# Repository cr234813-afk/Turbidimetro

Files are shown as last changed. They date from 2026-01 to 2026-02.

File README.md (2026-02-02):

# Turbidimetro
El acceso a agua de calidad es un pilar fundamental para el desarrollo sostenible y la salud pública; sin embargo, el monitoreo constante de cuerpos hídricos enfrenta barreras económicas debido al alto costo de los equipos de medición certificados. En este contexto, la turbidez, definida como la medida del grado de transparencia que pierde el agua por la presencia de partículas en suspensión, se presenta como uno de los indicadores más críticos para evaluar la potabilidad y el estado ecológico de los ecosistemas acuáticos.
El presente proyecto, surge como una respuesta tecnológica de bajo costo y código abierto. El núcleo del dispositivo se fundamenta en el método de transmitancia. Para garantizar el diseño conceptual se validó mediante herramientas de ingeniería como el QFD y matrices de selección como del apoyo del laboratorio de la EMAPS donde se realizaron algunas pruebas con un turbidímetro comercial, asegurando que nuestro prototipo pueda medir el valor de turbidez, sino también portátil y sencillo de utilizar en entornos de campo.
A diferencia de otros proyectos, integra un componente de ciencia ciudadana mediante una plataforma digital desarrollada en Google Sites y GitHub que son plataformas gratuitas. Esta infraestructura permite que los datos recolectados por los usuarios sean subidos mediante formularios dinámicos y visualizados en tiempo real en estas plataformas, fomentando la participación comunitaria en la vigilancia ambiental.

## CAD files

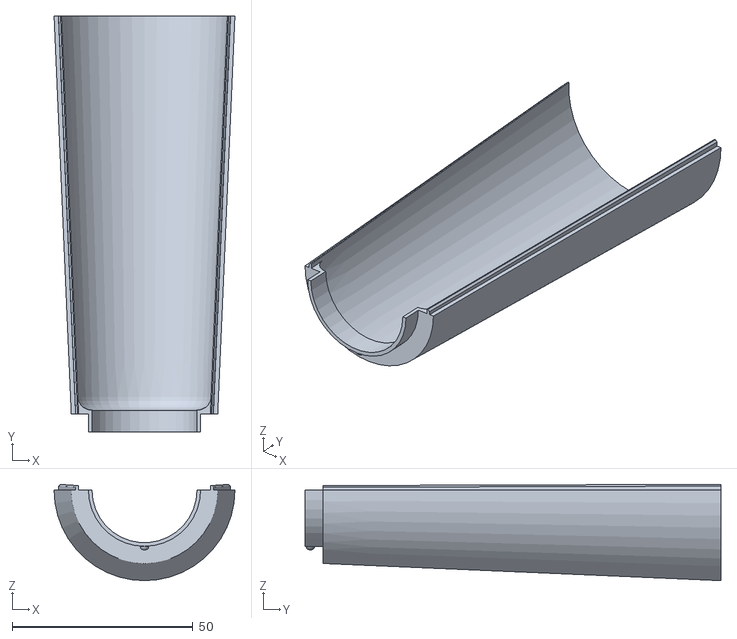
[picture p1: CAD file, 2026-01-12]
Imprimibles/Cuerpo_izquierdo.stl
50.0 x 115.0 x 26.6

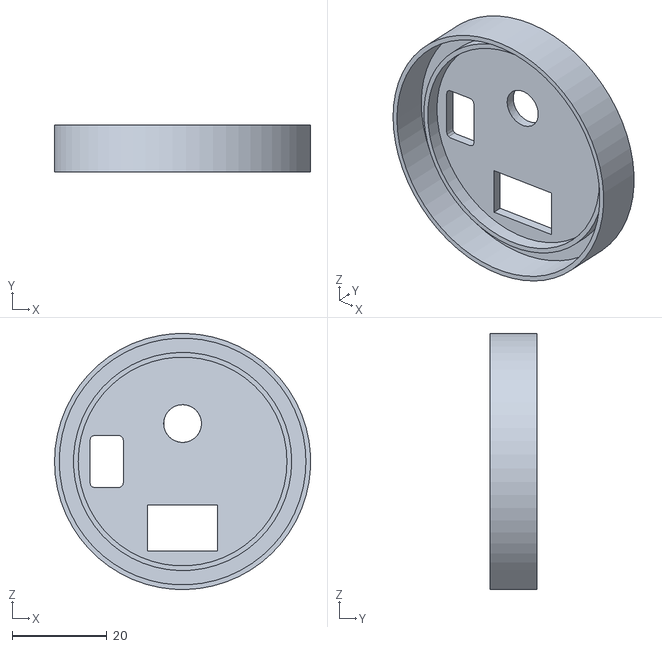
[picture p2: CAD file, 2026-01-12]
Imprimibles/Tapa_Superior.stl
54.0 x 10.0 x 54.0

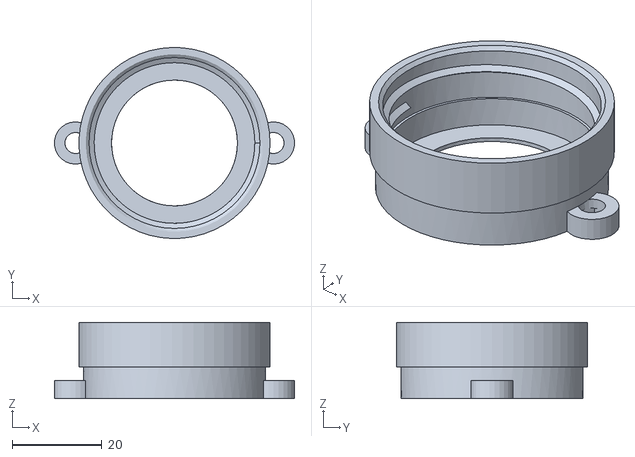
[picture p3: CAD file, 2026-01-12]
Imprimibles/Cuerpo_sensor_inferior.stl
53.4 x 42.5 x 17.0

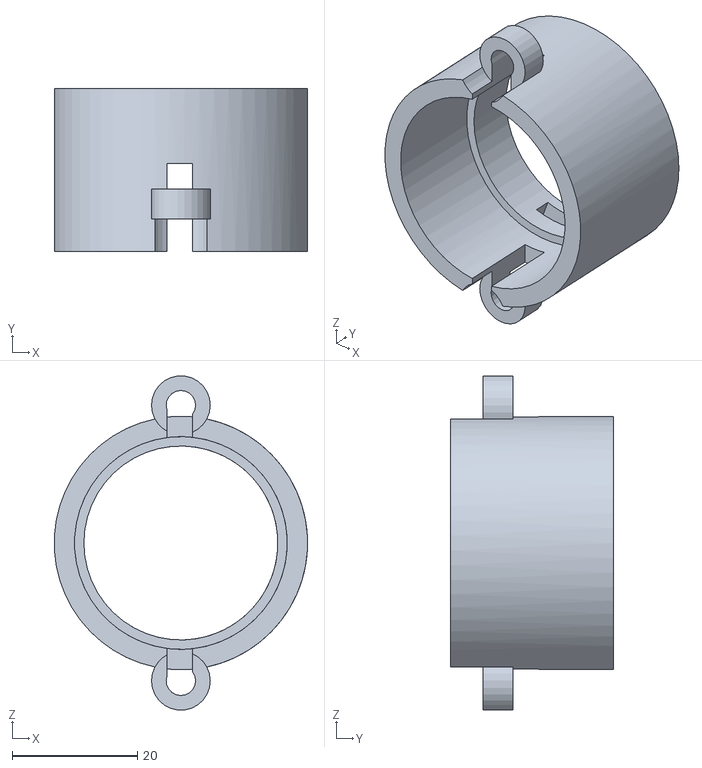
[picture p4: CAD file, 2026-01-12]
Imprimibles/Cuerpo_sensor_superior.stl
40.5 x 26.0 x 53.4

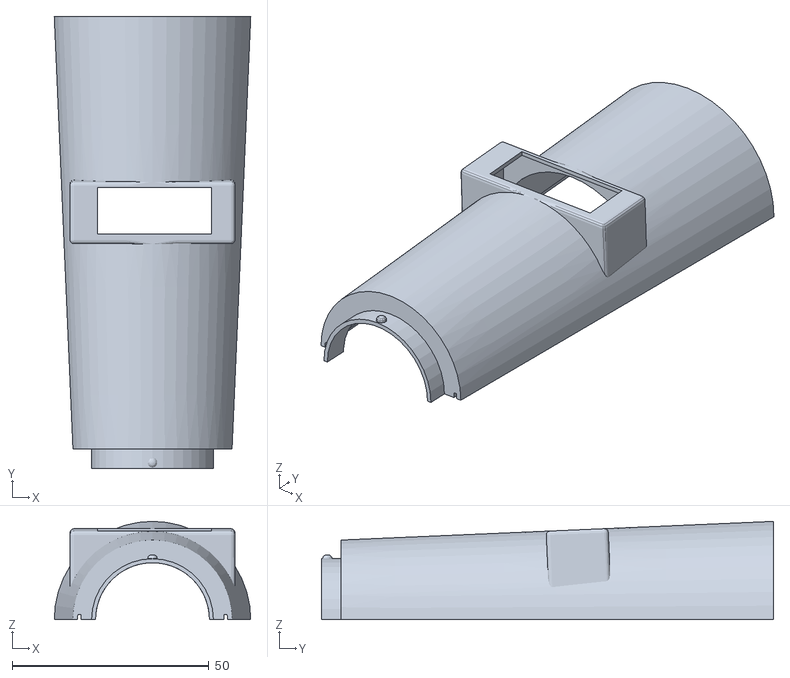
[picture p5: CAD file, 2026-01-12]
Imprimibles/Cuerpo_derecho.stl
50.0 x 115.0 x 25.0

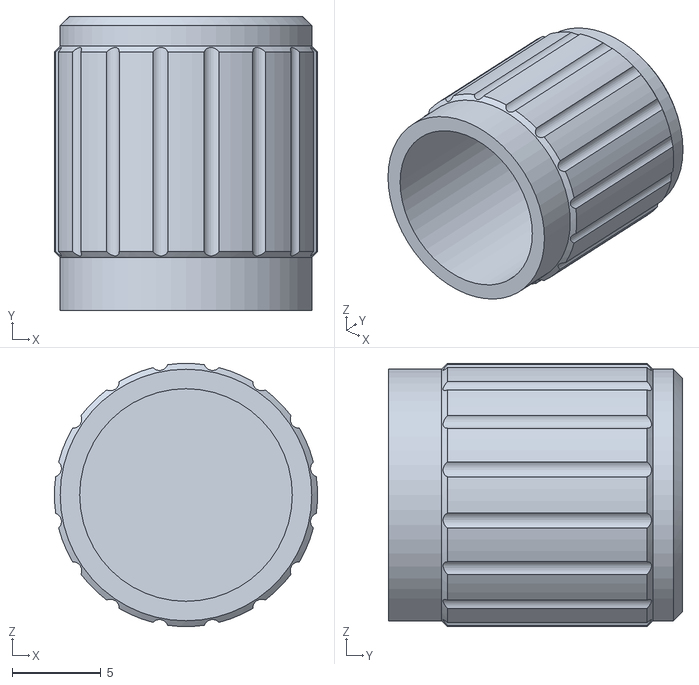
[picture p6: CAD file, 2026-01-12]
Imprimibles/Perilla_1.stl
14.8 x 16.6 x 14.8

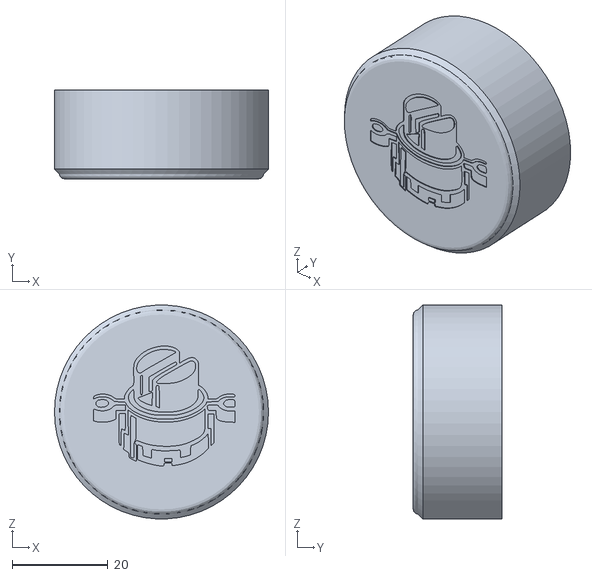
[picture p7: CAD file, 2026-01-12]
Imprimibles/Tapa_inferior.stl
44.7 x 18.5 x 44.6

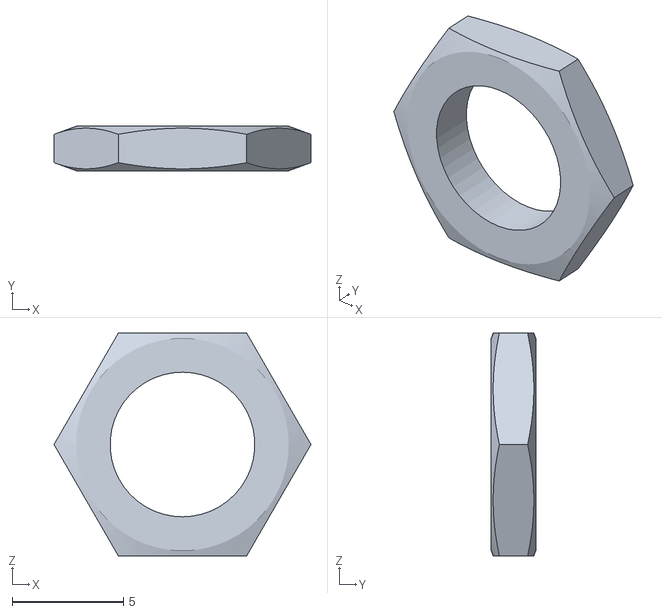
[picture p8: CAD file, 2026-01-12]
Imprimibles/Tuerca_sujecion.stl
11.5 x 2.00 x 10.0

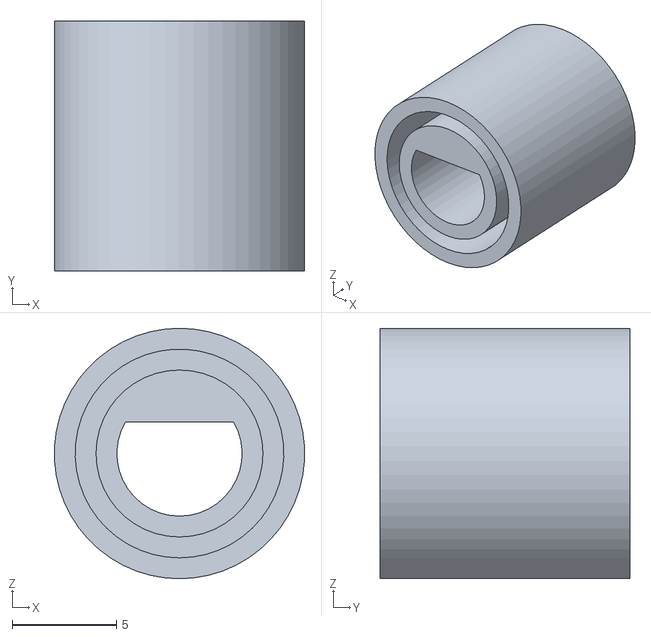
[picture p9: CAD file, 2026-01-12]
Imprimibles/Perilla_2.stl
12.0 x 12.0 x 12.0

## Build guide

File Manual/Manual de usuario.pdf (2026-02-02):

# Manual de usuario

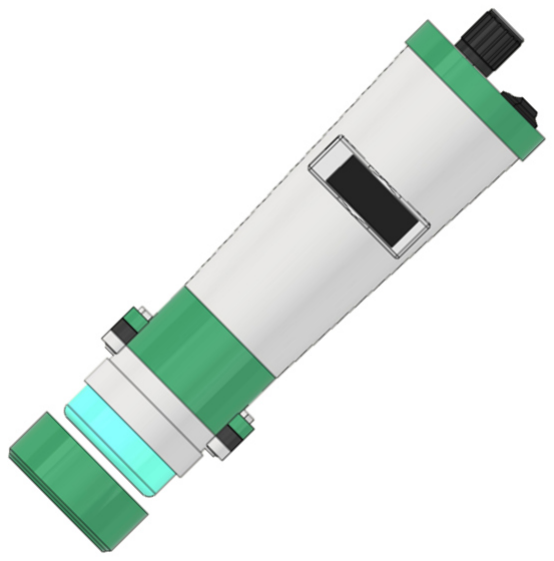
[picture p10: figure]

# Índice

### - Introducción - Requisitos previos - Lista de Materiales - Instrucciones de Impresión 3D - Calibración - Electrónica y Cableado - Programación - Montaje - Solución de Problemas - Conclusión y Contribuciones

# Introducción

- ¿Alguna vez te has preguntado cómo miden qué tan limpia está el agua? Para eso se usa el turbidímetro. Es un equipo que analiza la cantidad de partículas suspendidas en un líquido para saber qué tan transparente es realmente.
- El objetivo de este proyecto es desarrollar un turbidímetro de código abierto que rompa las barreras de costo y acceso a tecnología científica de calidad del Ecuador. A diferencia de los equipos comerciales, que suelen ser costosos y cerrados, este dispositivo combina la versatilidad de la impresión 3D con la potencia de la electrónica accesible y la programación.

# Requisitos previos

Impresora 3D

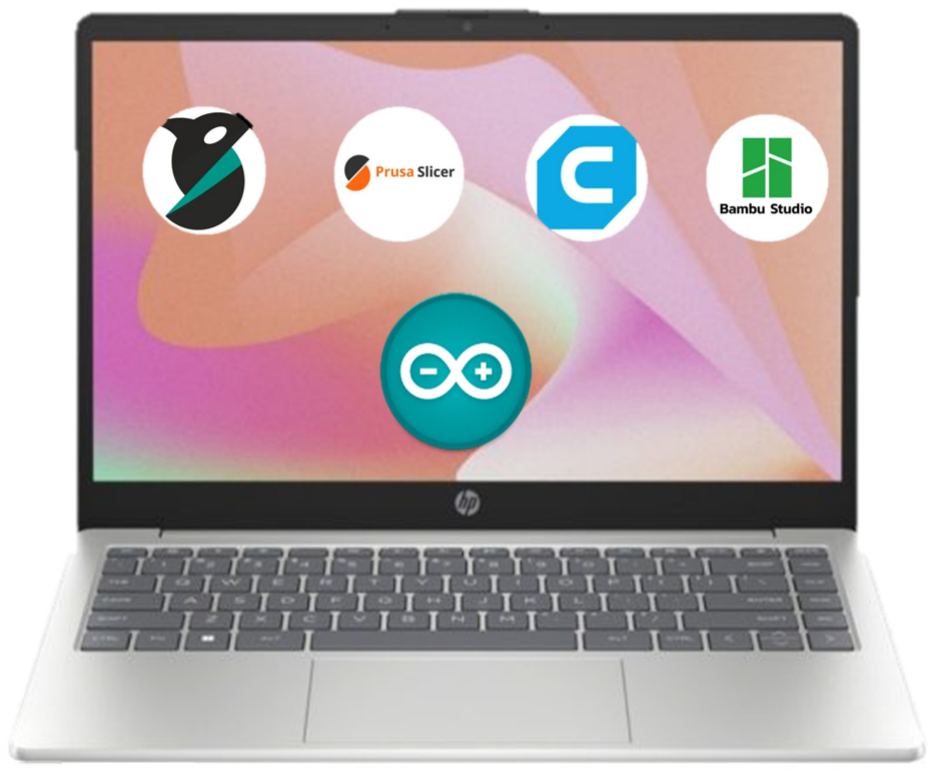
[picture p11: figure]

Computadora

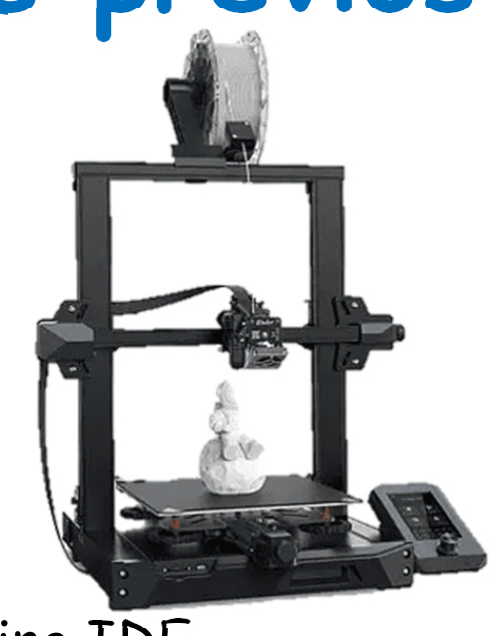
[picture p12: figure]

Software Arduino IDE

Software Slicer 3D

Kit de soldadura

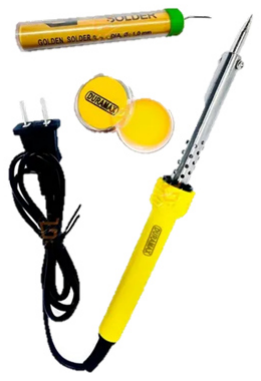
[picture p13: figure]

# Lista de partes y materiales

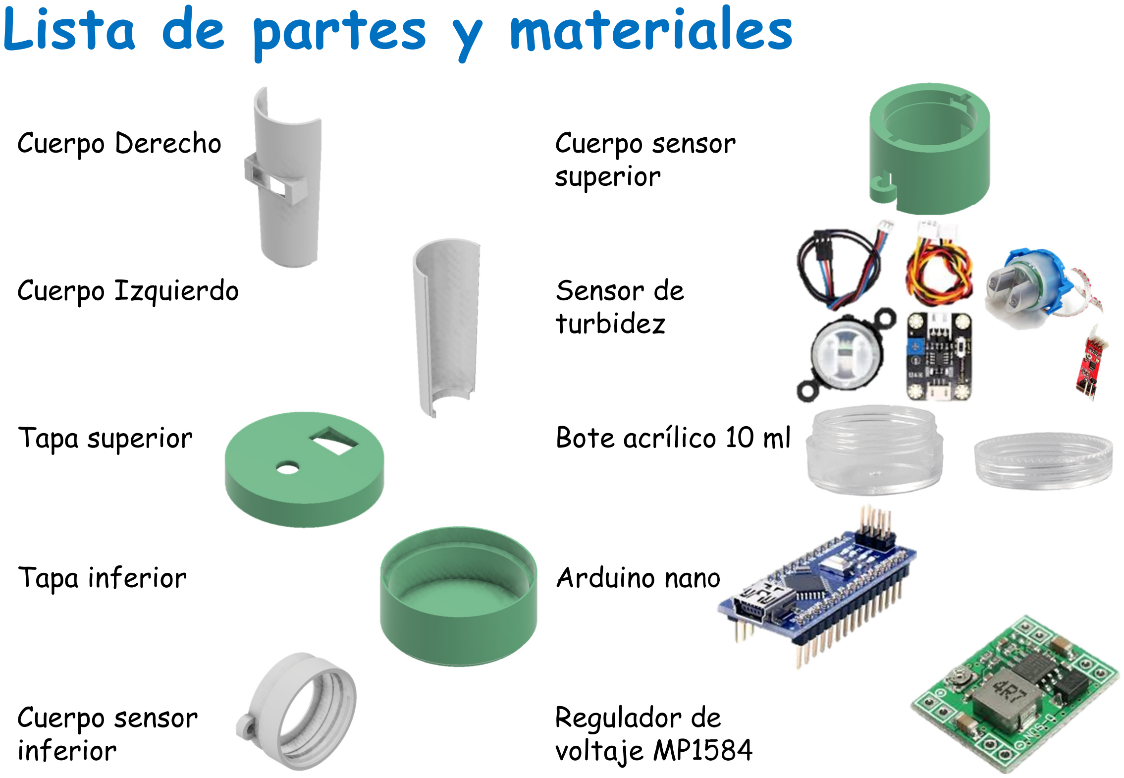
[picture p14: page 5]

Cuerpo sensor
superior

Cuerpo Derecho

Sensor de
turbidez

Cuerpo Izquierdo

Bote acrílico 10 mlTapa superior

Arduino nanoTapa inferior

Regulador de
voltaje MP1584

Cuerpo sensor
inferior

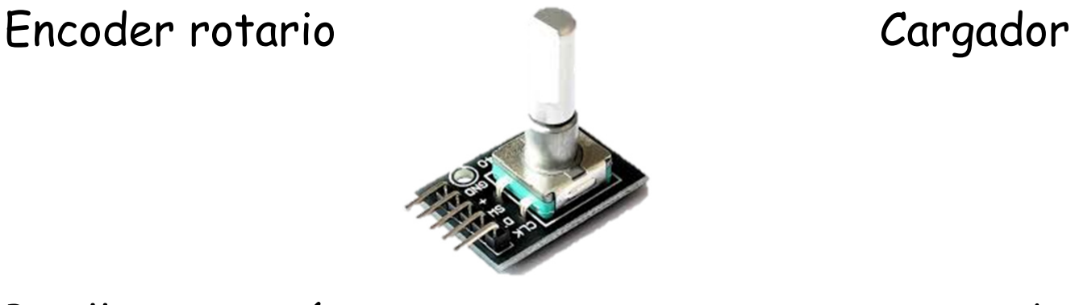
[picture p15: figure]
CargadorEncoder rotario
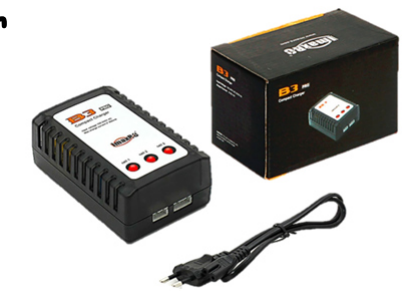
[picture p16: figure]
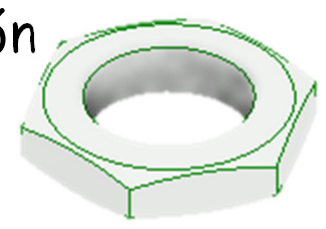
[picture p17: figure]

Turca de sujeción Perilla potenciómetro

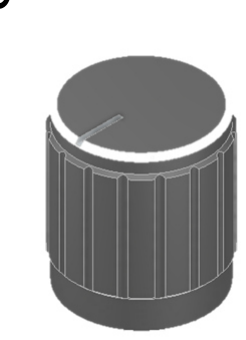
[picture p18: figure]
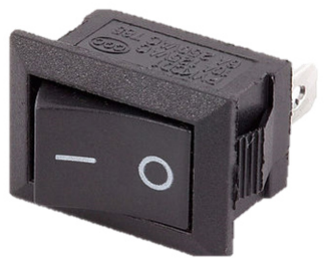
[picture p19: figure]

Inserto M4Switch

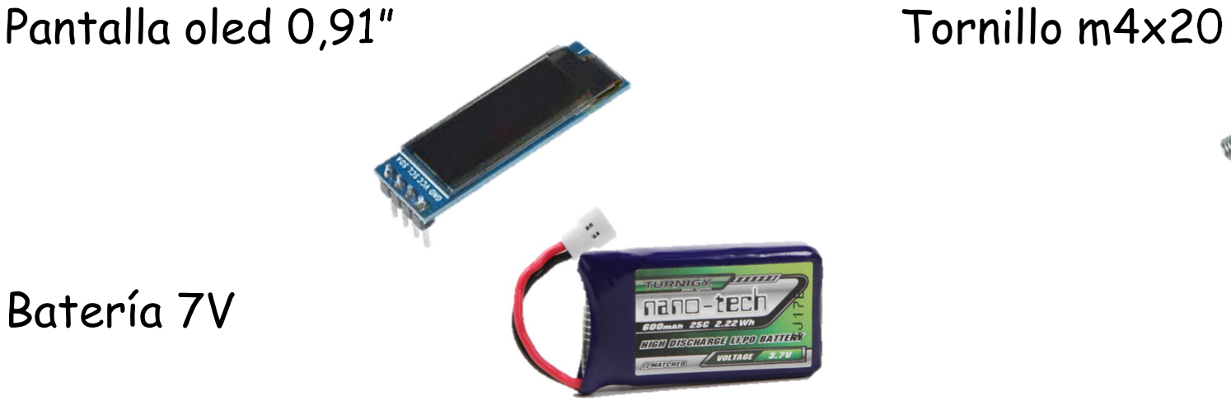
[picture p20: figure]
Tornillo m4x20Pantalla oled 0,91”; Batería 7V

# Instrucciones de Impresión 3D

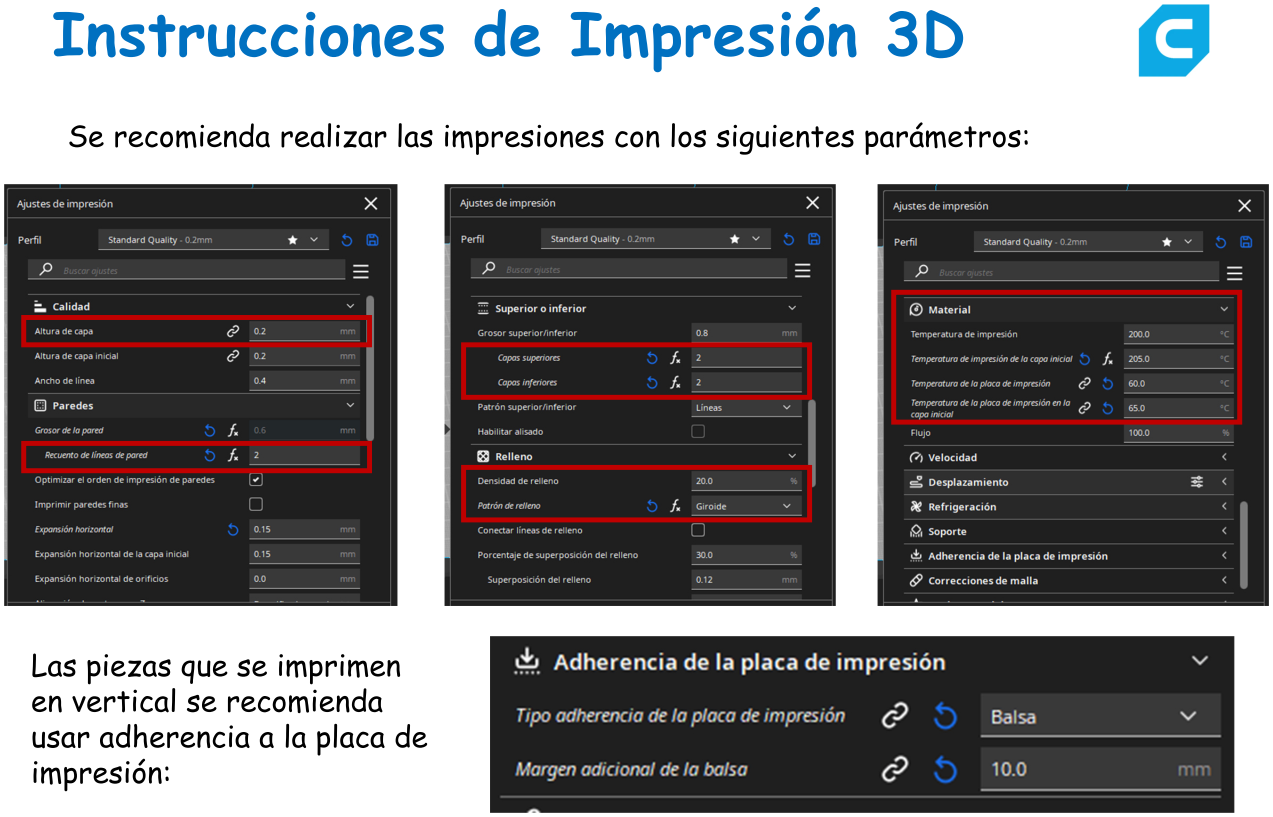
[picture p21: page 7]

Se recomienda realizar las impresiones con los siguientes parámetros:

Las piezas que se imprimen en vertical se recomienda
usar adherencia a la placa de impresión:

# Electrónica y Cableado

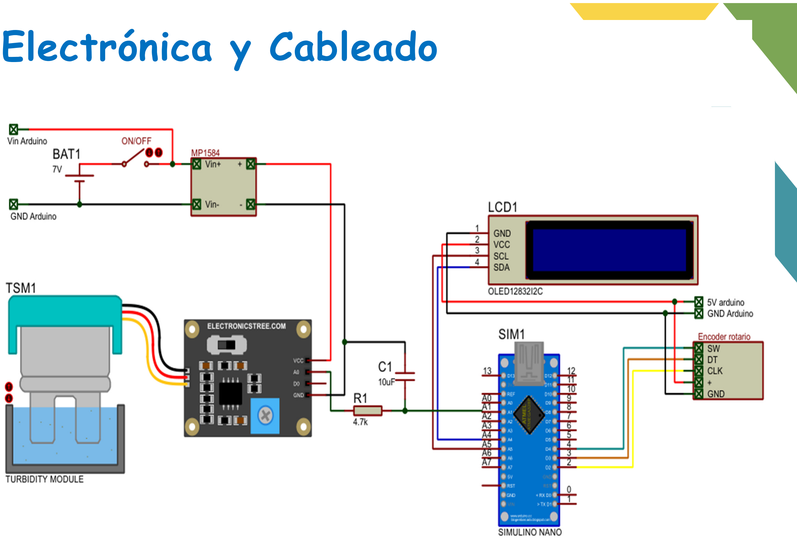
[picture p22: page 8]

### 1. Cargamos el programa Calibración_previa

### 2. Colocamos una muestra de agua destilada

### 3. Cargamos el programa y revisamos en el serial que el voltaje

sea 4,2 V

### 4. Si no esta cerca de este valor vamos a girar la perilla de la

placa de acondicionamiento hasta que cambie en el serial

### 5. Listo tu turbidímetro esta calibrado

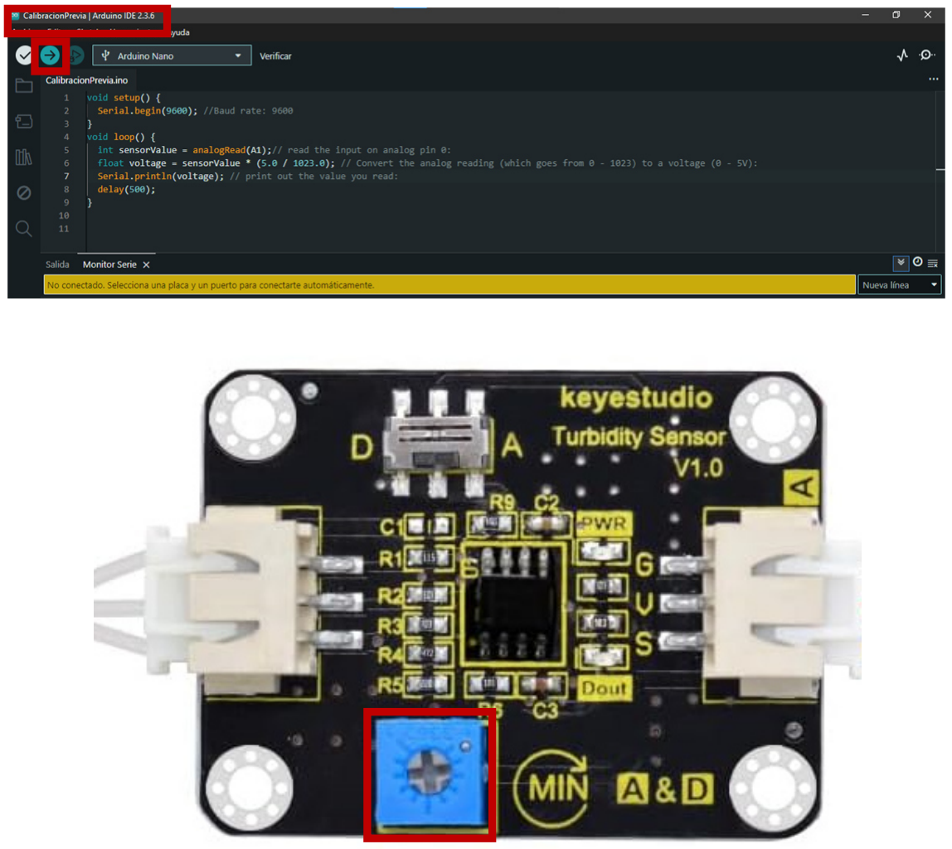
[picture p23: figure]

# Calibración

# Programación

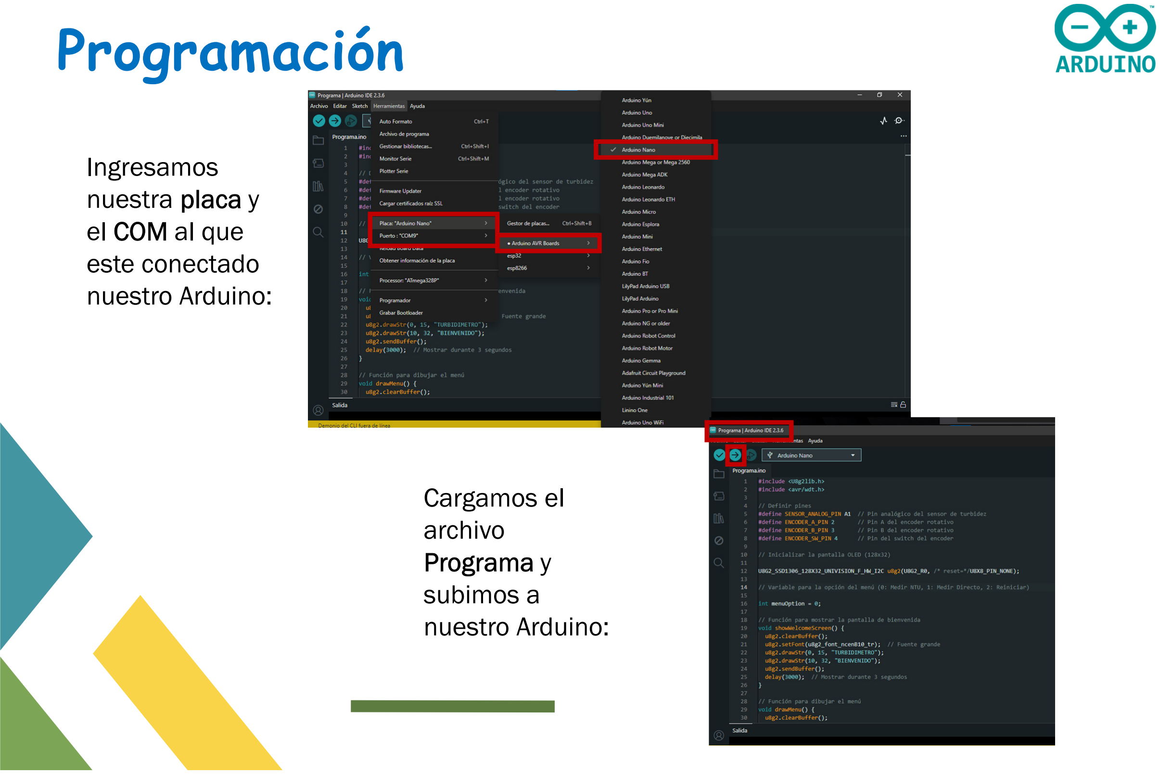
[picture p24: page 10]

Ingresamos
nuestra placa y
el COM al que
este conectado
nuestro Arduino:

Cargamos el
archivo
Programa y
subimos a
nuestro Arduino:

# Montaje

## Montaje turbidímetro

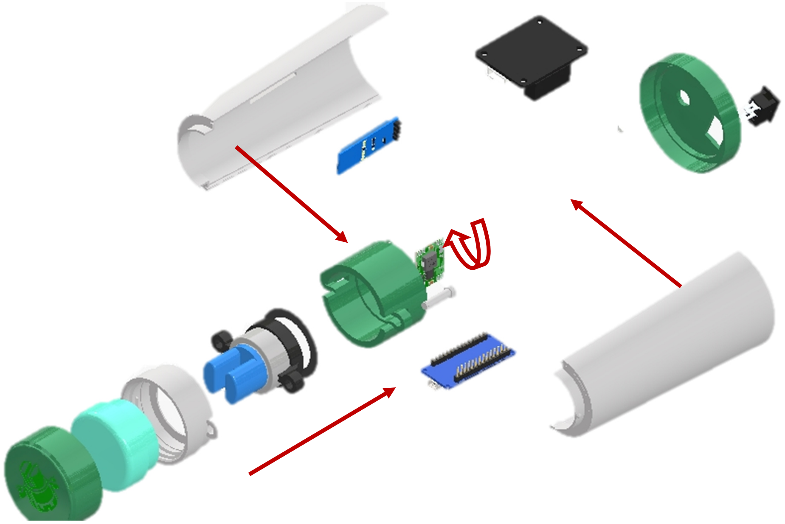
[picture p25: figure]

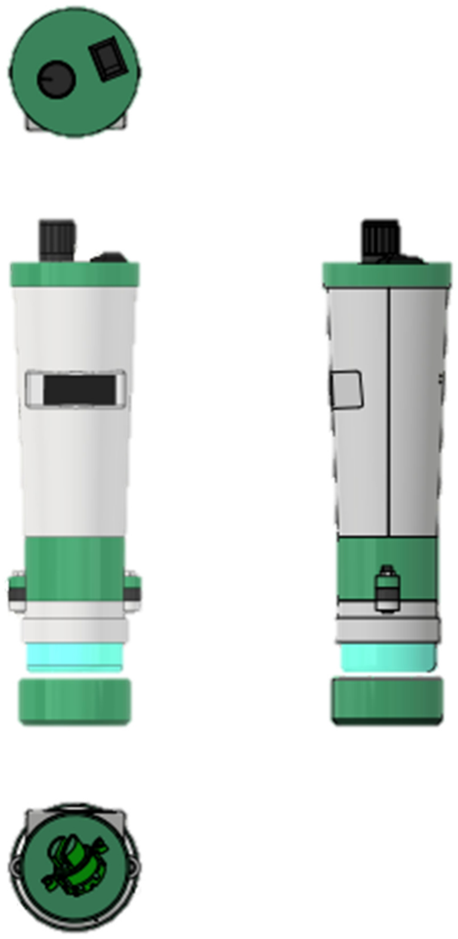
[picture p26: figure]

Comunícate con nosotros a nuestro correo

¿Mi sensor esta realizando medidas erróneas?
Revisa el archivo de Calibracion_previa en Arduino IDE, además usa agua destilada para realiza la calibración; cuando cargues el programa modifica que el valor de voltaje este en 4.2V (Voltios) si no es asi regula con el potenciómetro que se encuentra en la tarjeta de acondicionamiento del sensor de turbidez.
Revisa que el valor de voltaje que llega al sensor sea de 5V(Voltios). ¿Por qué mi lectura varía si muevo el dispositivo ?
El método de transmitancia es sensible a la luz ambiental. Asegúrate de que la tapa de la cámara del sensor impresa en 3D esté completamente cerrada durante la medición. Además utiliza el estabilizador para que las medidas no se alteren.

# Solución de Problemas

Conclusión

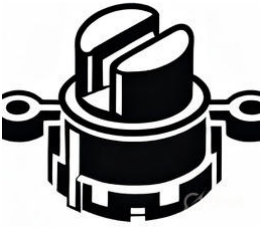
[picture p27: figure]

Se validó exitosamente el prototipo en los laboratorios de la EPMAPS, obteniendo un coeficiente de determinación R^2 superior a 0,98 en el análisis de regresión realizado en Minitab. Esto confirma que el método de transmitancia es altamente confiable para medir niveles de turbidez en rangos medios y altos.

## Gracias

Christian Perrazo
+593 958 761 443
christianperrazoo@gmail.com

Bryan Mayo
+593-983005490
bsmayo21@gmail.com

https://sites.google.com/view/turbidimetro

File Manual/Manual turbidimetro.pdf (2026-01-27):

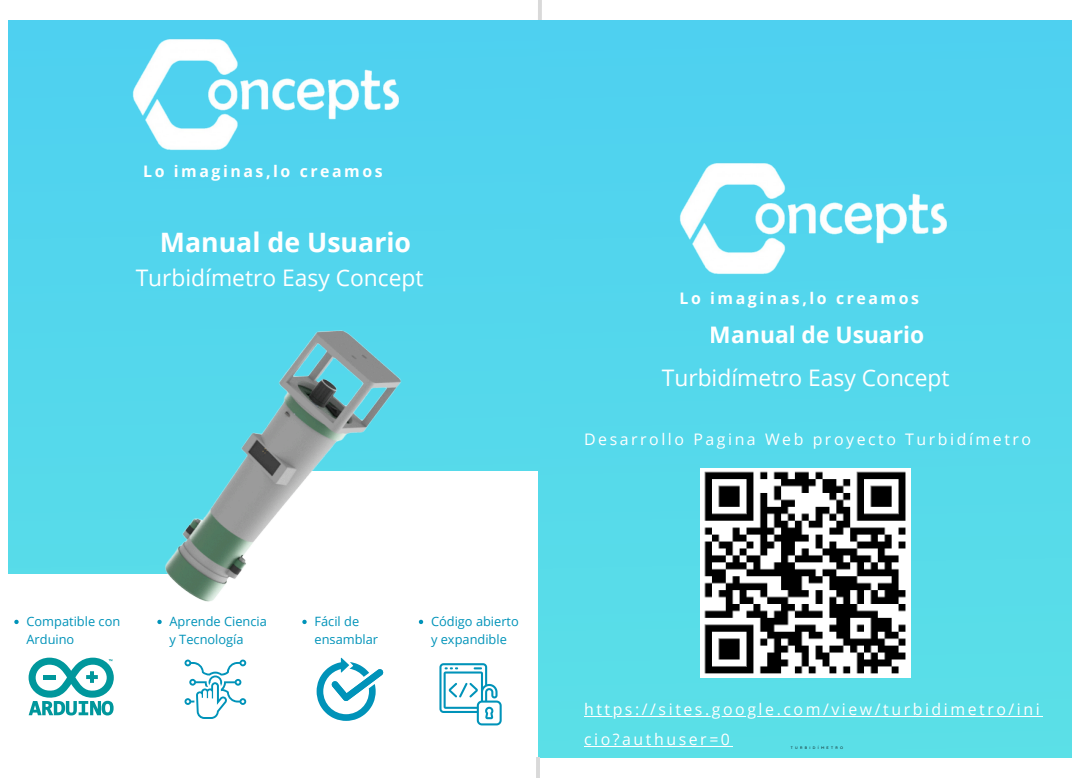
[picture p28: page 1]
Compatible con Arduino; Aprende Ciencia y Tecnología; Fácil de ensamblar; Código abierto y expandible

L o ima g ina s , l o c r e amo s
Manual de Usuario
Turbidímetro Easy Concept

## Manual de Usuario

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

1

Turbidímetro Easy Concept | Turbidímetro Easy Concept

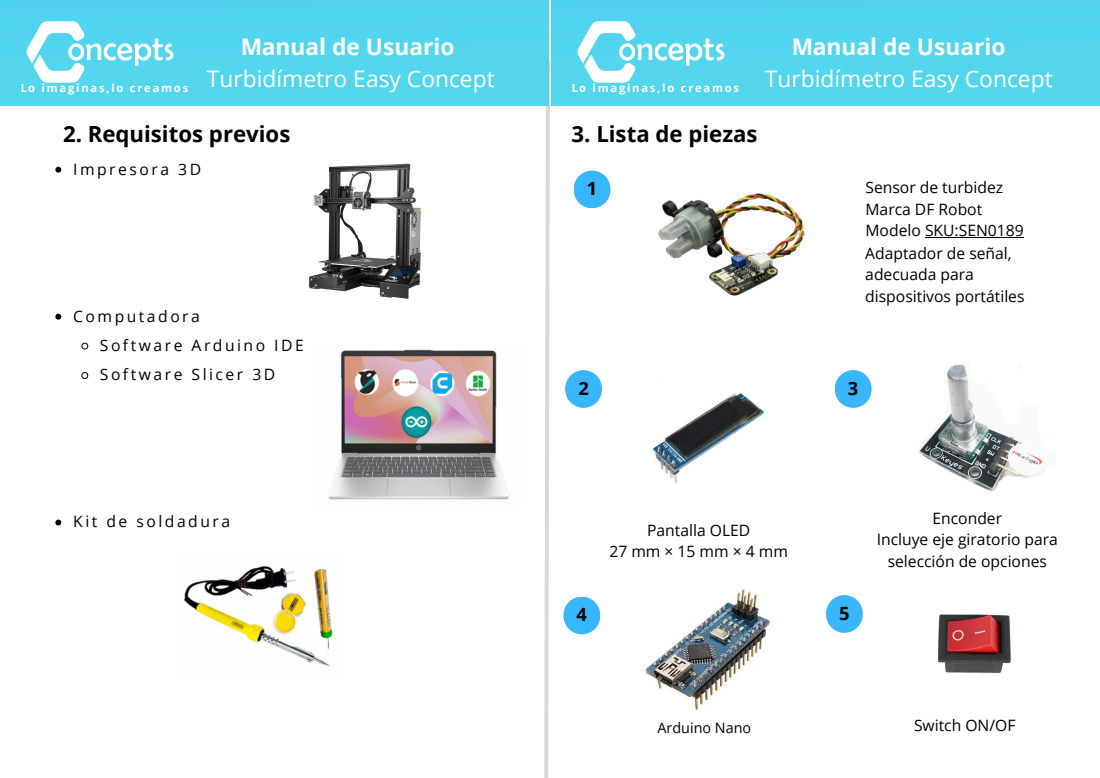
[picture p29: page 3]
Enconder; Arduino Nano; Switch ON/OF; dispositivos portátiles

L o ima g ina s , l o c r e amo s

2. Requisitos previos I m p r e s o r a 3 D | | 3. Lista de piezas | Modelo SKU:SEN0189 (https://www.dfrobot.com/product-1394.html) Adaptador de señal, adecuada para

Sensor de turbidez
Marca DF Robot

Pantalla OLED

Incluye eje giratorio para
selección de opciones

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

8

7

Electrónica

Impresión 3D (carcasa)

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

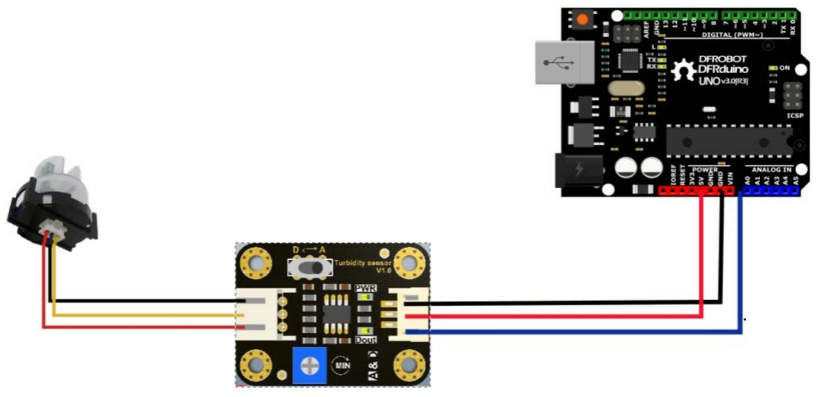
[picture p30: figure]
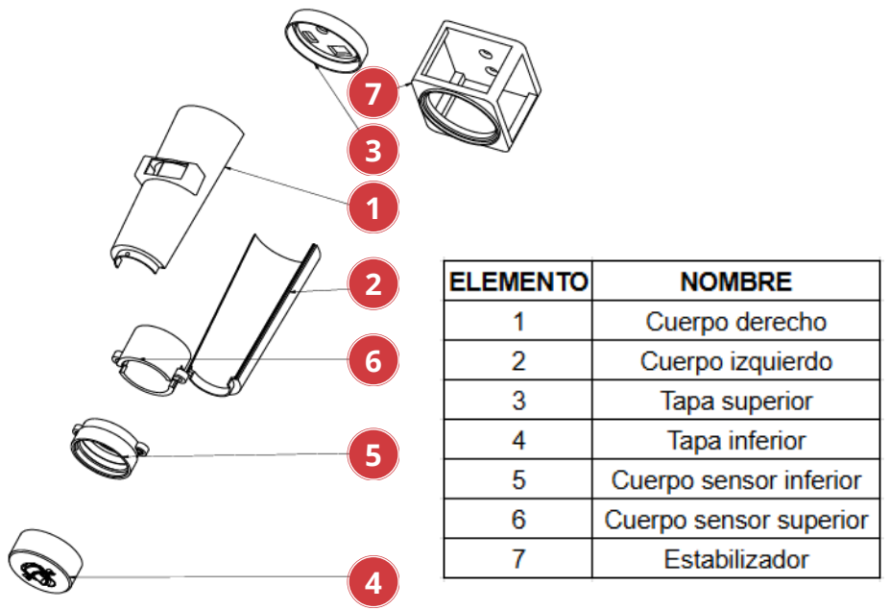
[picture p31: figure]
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

## 5.1 Calibración sensor turbidez

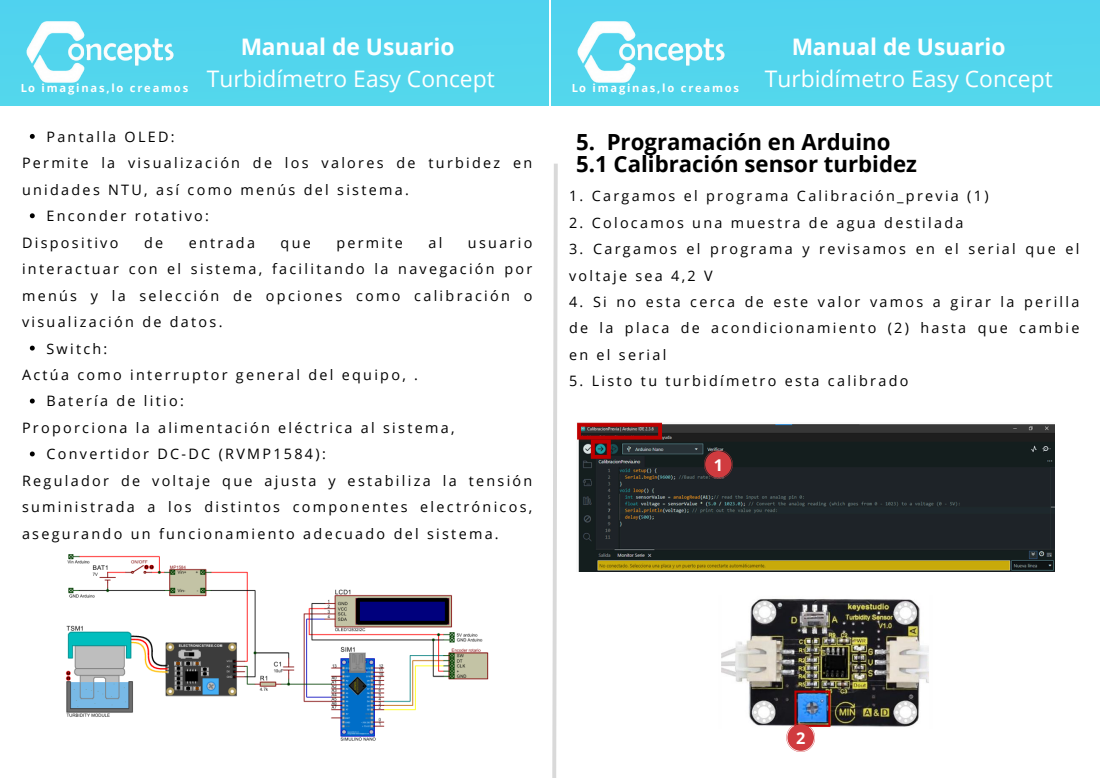
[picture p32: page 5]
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

Turbidímetro Easy Concept L o ima g ina s , l o c r e amo s | Turbidímetro Easy Concept L o ima g ina s , l o c r e amo s

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

# Manual de Fabricación

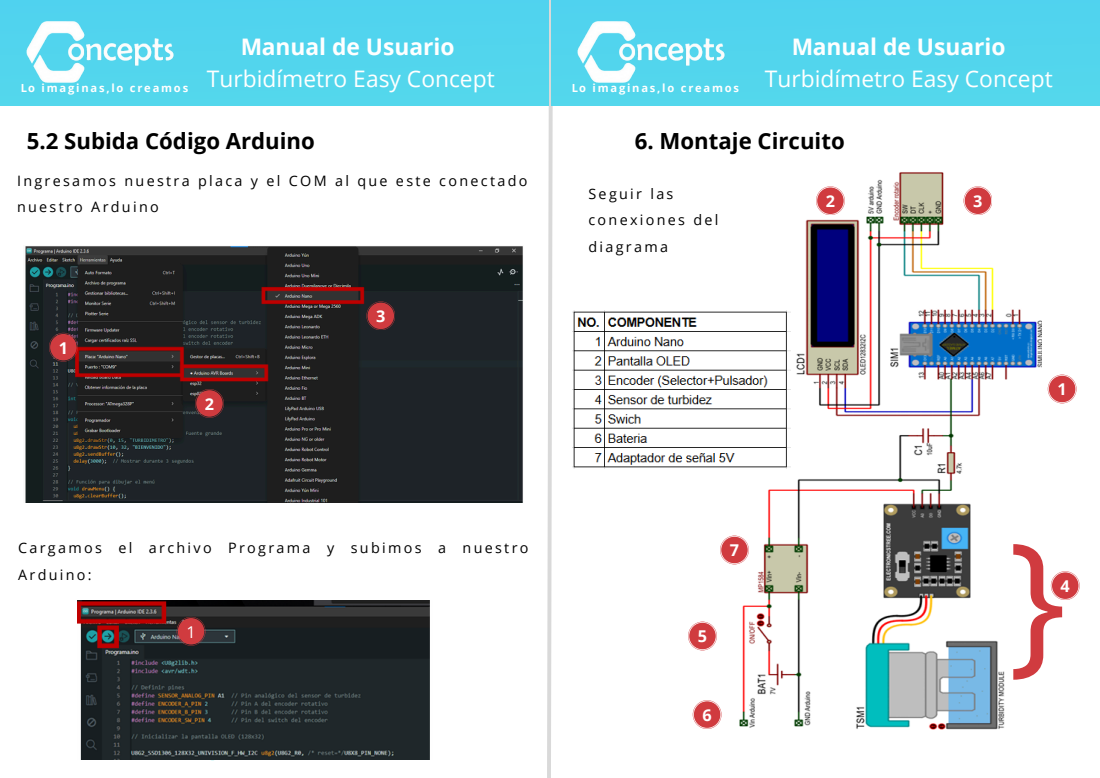
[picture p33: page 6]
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

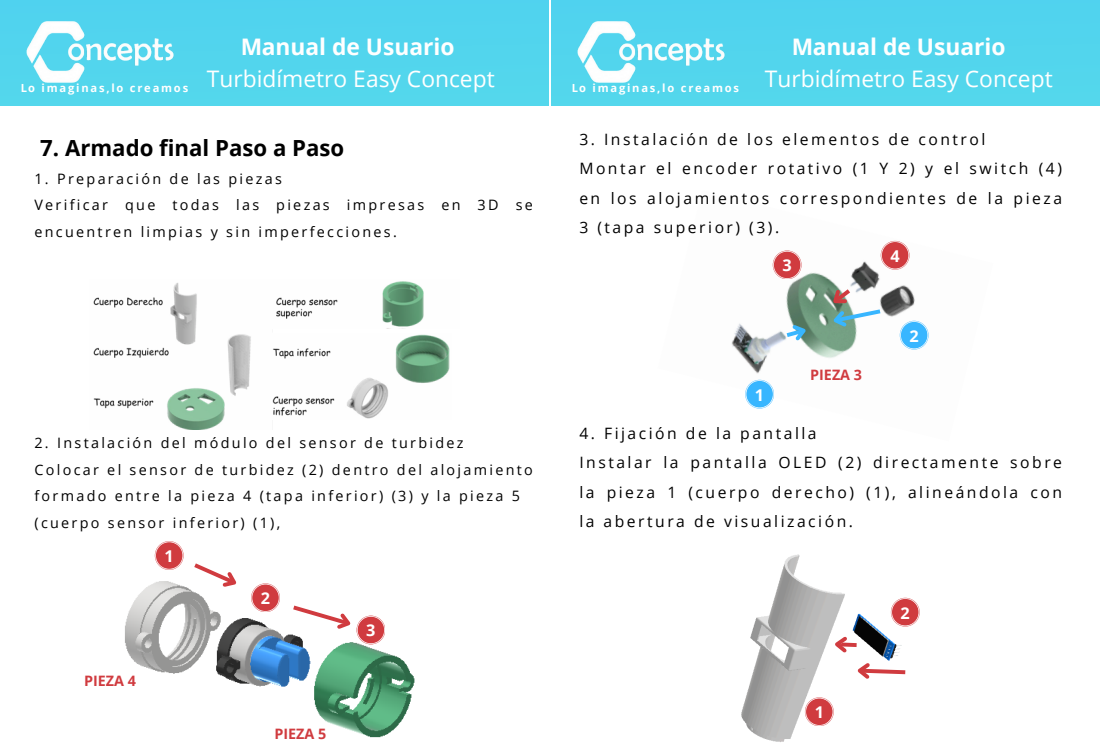
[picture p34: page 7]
PIEZA 4; PIEZA 5; PIEZA 3

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

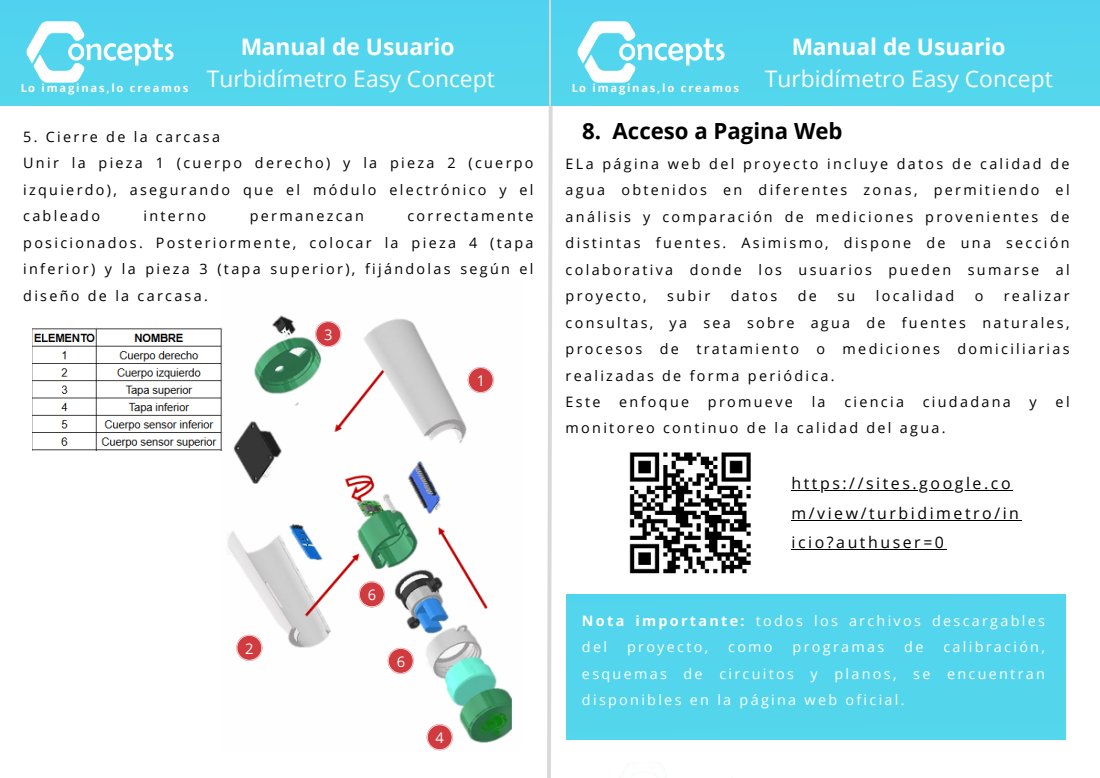
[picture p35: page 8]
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

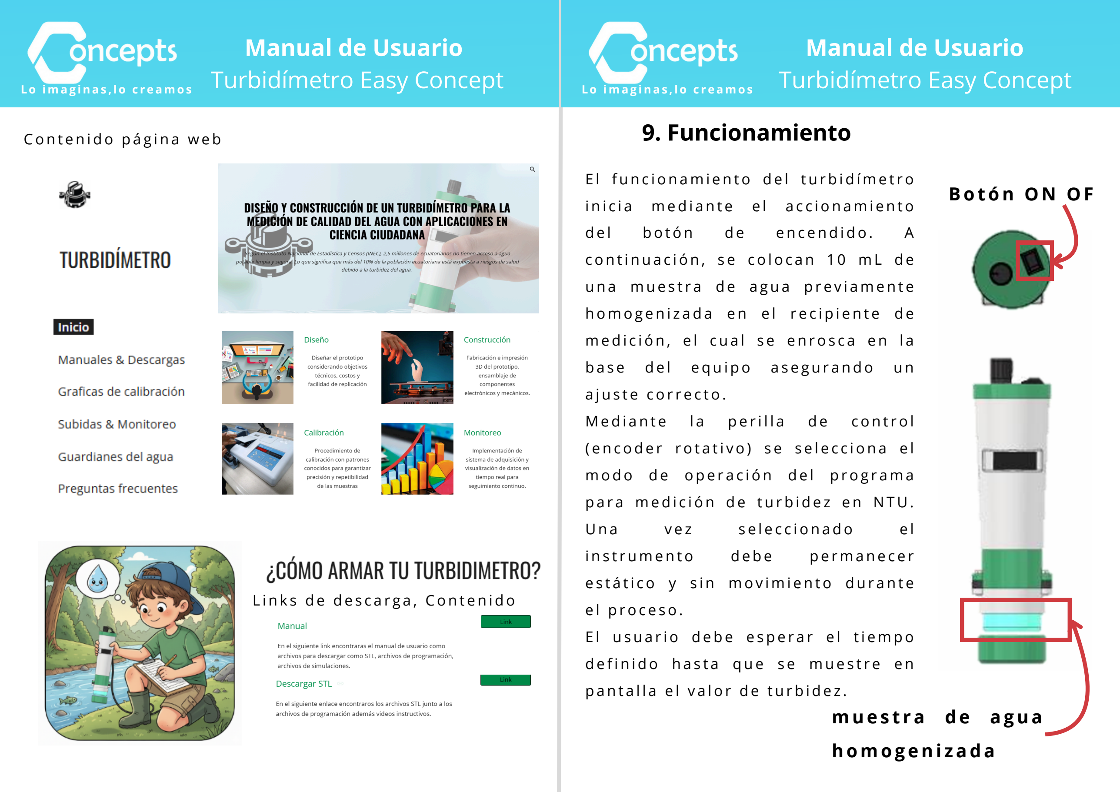
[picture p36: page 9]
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

### mue s t r a d e a gua homo g eni z a d a

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

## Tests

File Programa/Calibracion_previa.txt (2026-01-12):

void setup() {
  Serial.begin(9600); // Rango de baudios: 9600
}
void loop() {
  int sensorValue = analogRead(A1);// Leemos la entrada analogica del pin 0:
  float voltage = sensorValue * (5.0 / 1023.0); // Convertimos la rectura analogica (esta varia de 0 - 1023) este sera nuestro voltaje en el rango (0 - 5V):
  Serial.println(voltage); // imprimimos el valor de salida leído:
  delay(500);
}

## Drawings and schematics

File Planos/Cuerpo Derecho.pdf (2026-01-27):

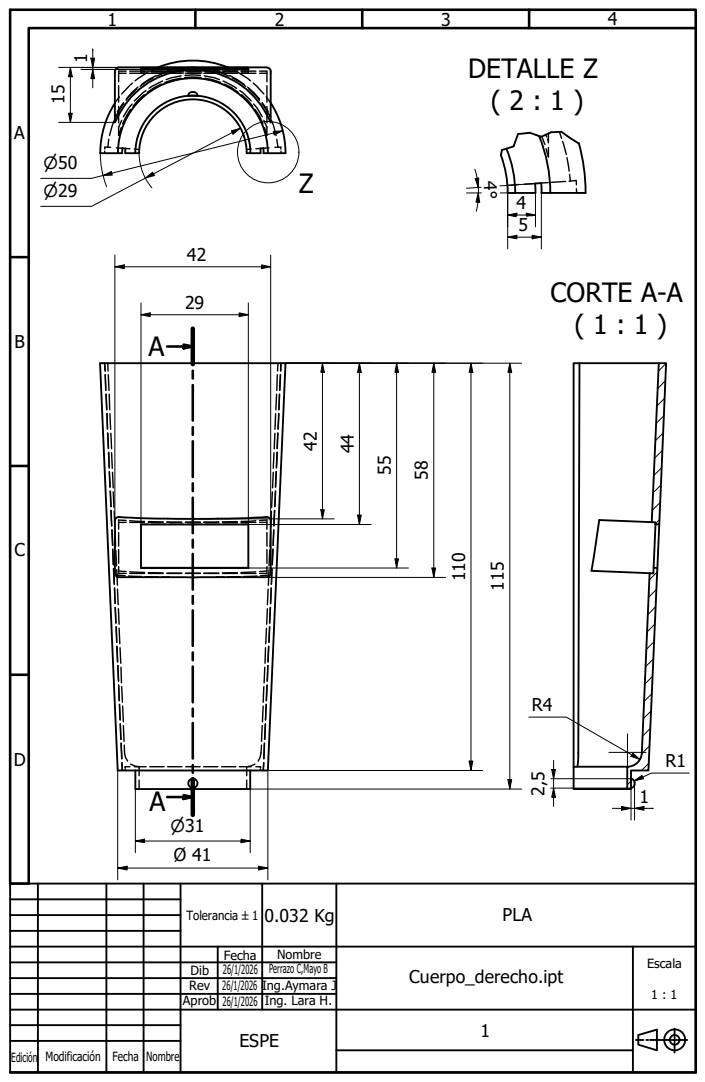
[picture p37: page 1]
CORTE A-A ( 1 : 1 ); DETALLE Z ( 2 : 1 )

Tolerancia `1 | 0.032 Kg | PLA

Fecha | Nombre | Cuerpo_derecho.ipt | Escala 1 : 1
Dib | 26/1/2026 | Perrazo C,Mayo B
Rev | 26/1/2026 | Ing.Aymara J
Aprob | 26/1/2026 | Ing. Lara H.

ESPE | 1

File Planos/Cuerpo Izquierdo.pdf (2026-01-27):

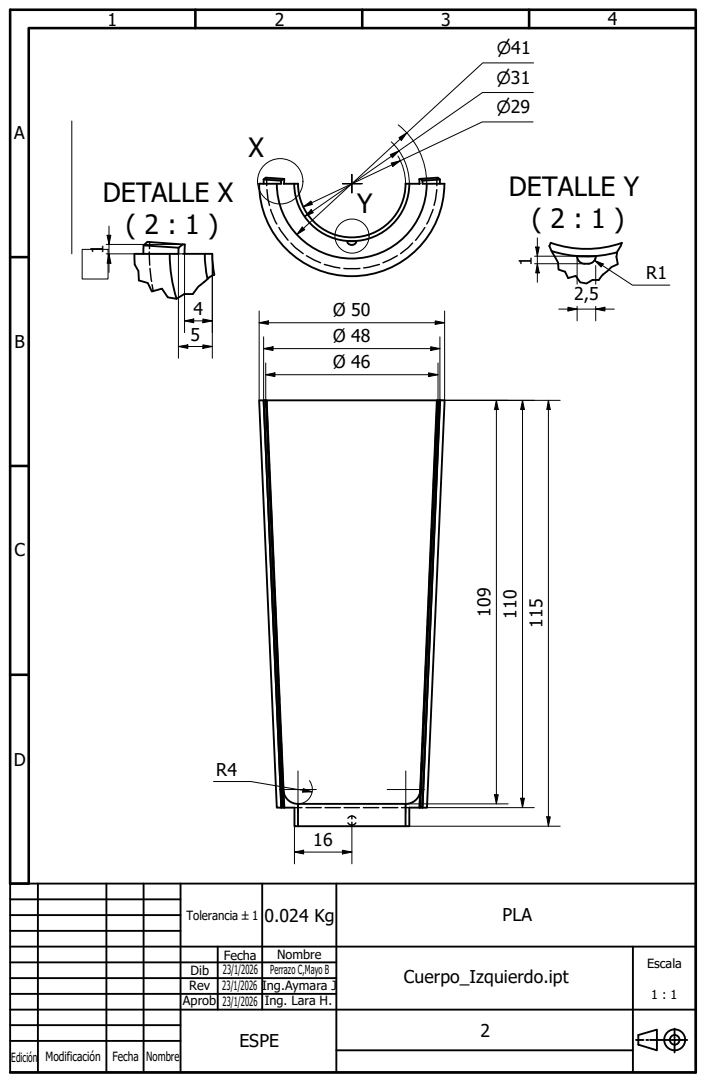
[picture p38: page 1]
DETALLE X ( 2 : 1 ); DETALLE Y ( 2 : 1 )

Tolerancia `1 | 0.024 Kg | PLA

Fecha | Nombre | Cuerpo_Izquierdo.ipt | Escala 1 : 1
Dib | 23/1/2026 | Perrazo C,Mayo B
Rev | 23/1/2026 | Ing.Aymara J
Aprob | 23/1/2026 | Ing. Lara H.

ESPE | 2

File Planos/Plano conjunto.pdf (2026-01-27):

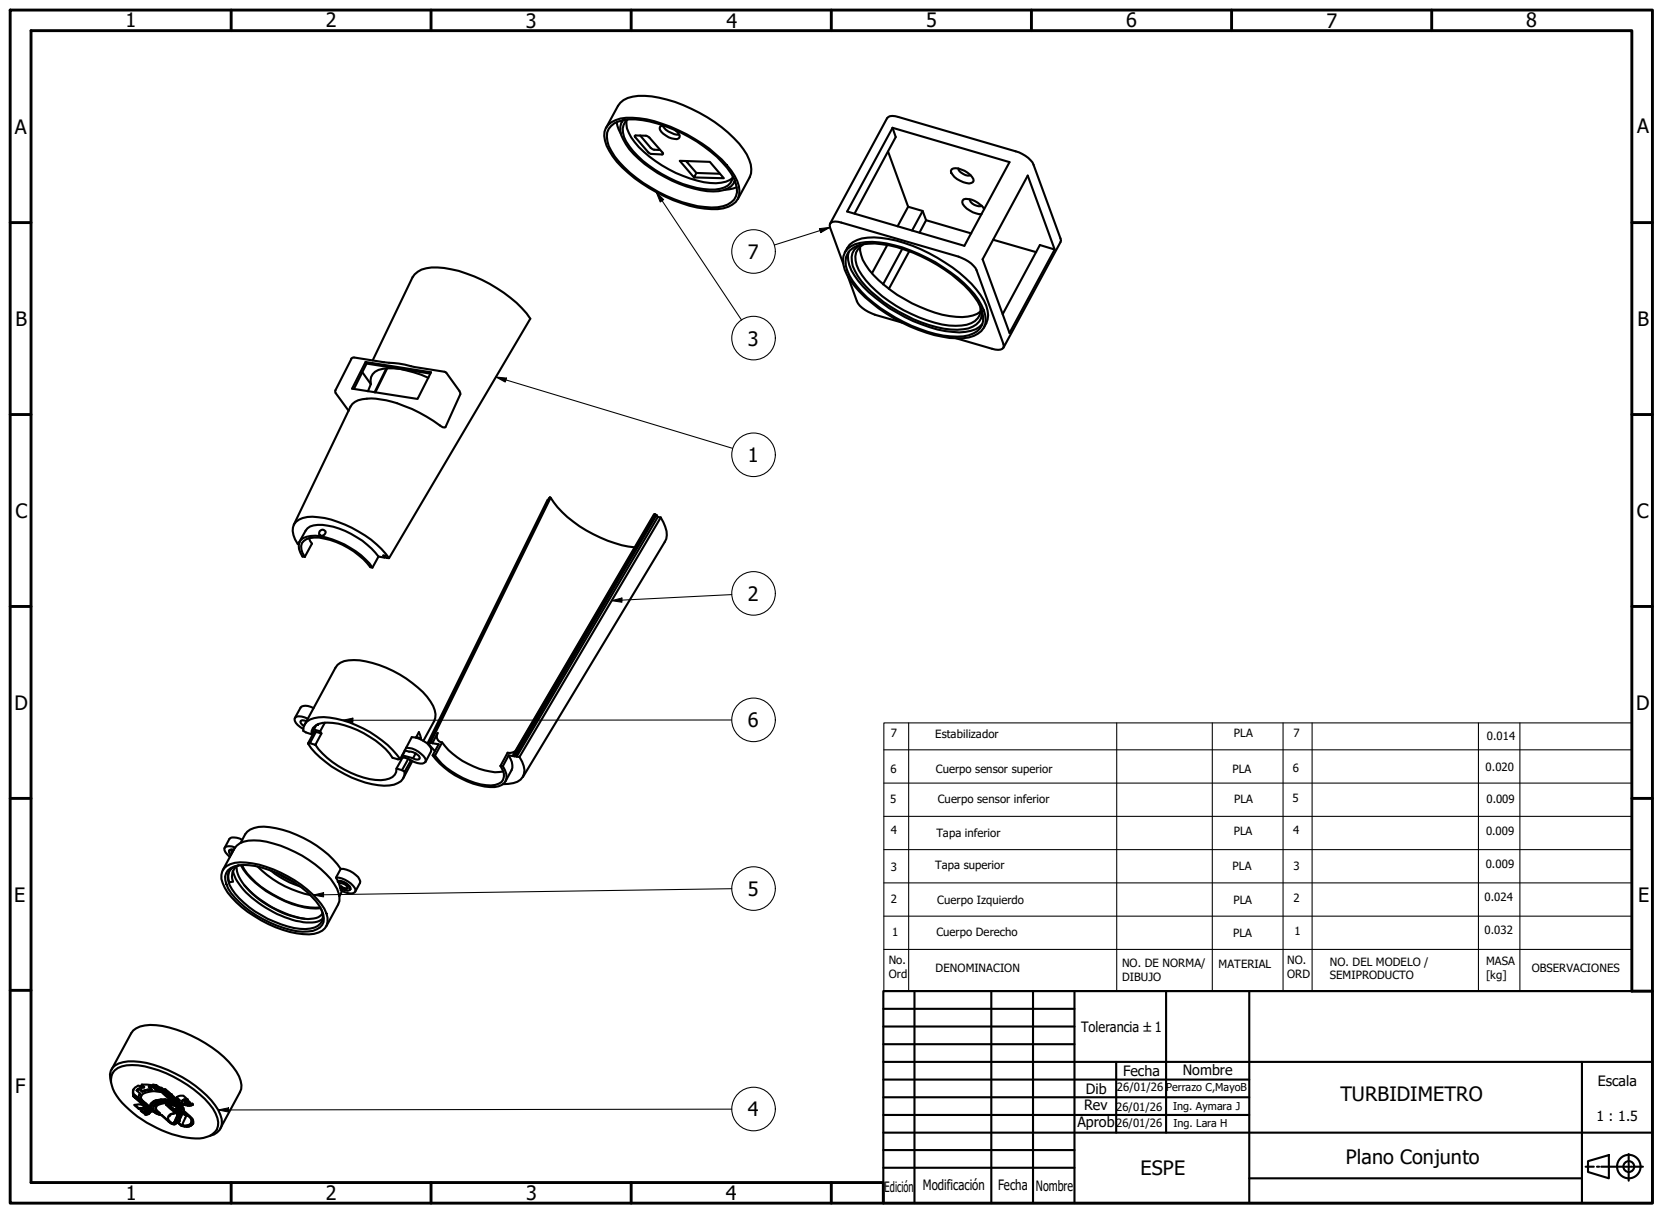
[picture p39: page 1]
Tolerancia `1

7 | Estabilizador | PLA | 7 | 0.014

6 | Cuerpo sensor superior | PLA | 6 | 0.020

5 | Cuerpo sensor inferior | PLA | 5 | 0.009

4 | Tapa inferior | PLA | 4 | 0.009

3 | Tapa superior | PLA | 3 | 0.009

2 | Cuerpo Izquierdo | PLA | 2 | 0.024

1 | Cuerpo Derecho | PLA | 1 | 0.032

NO. DEL MODELO /
SEMIPRODUCTO

NO. DE NORMA/
DIBUJO

Fecha | Nombre | TURBIDIMETRO | Escala 1 : 1.5
Dib | 26/01/26 Perrazo C,MayoB
Rev | 26/01/26 | Ing. Aymara J
Aprob | 26/01/26 | Ing. Lara H

ESPE | Plano Conjunto

Edición | Modificación | Fecha | Nombre

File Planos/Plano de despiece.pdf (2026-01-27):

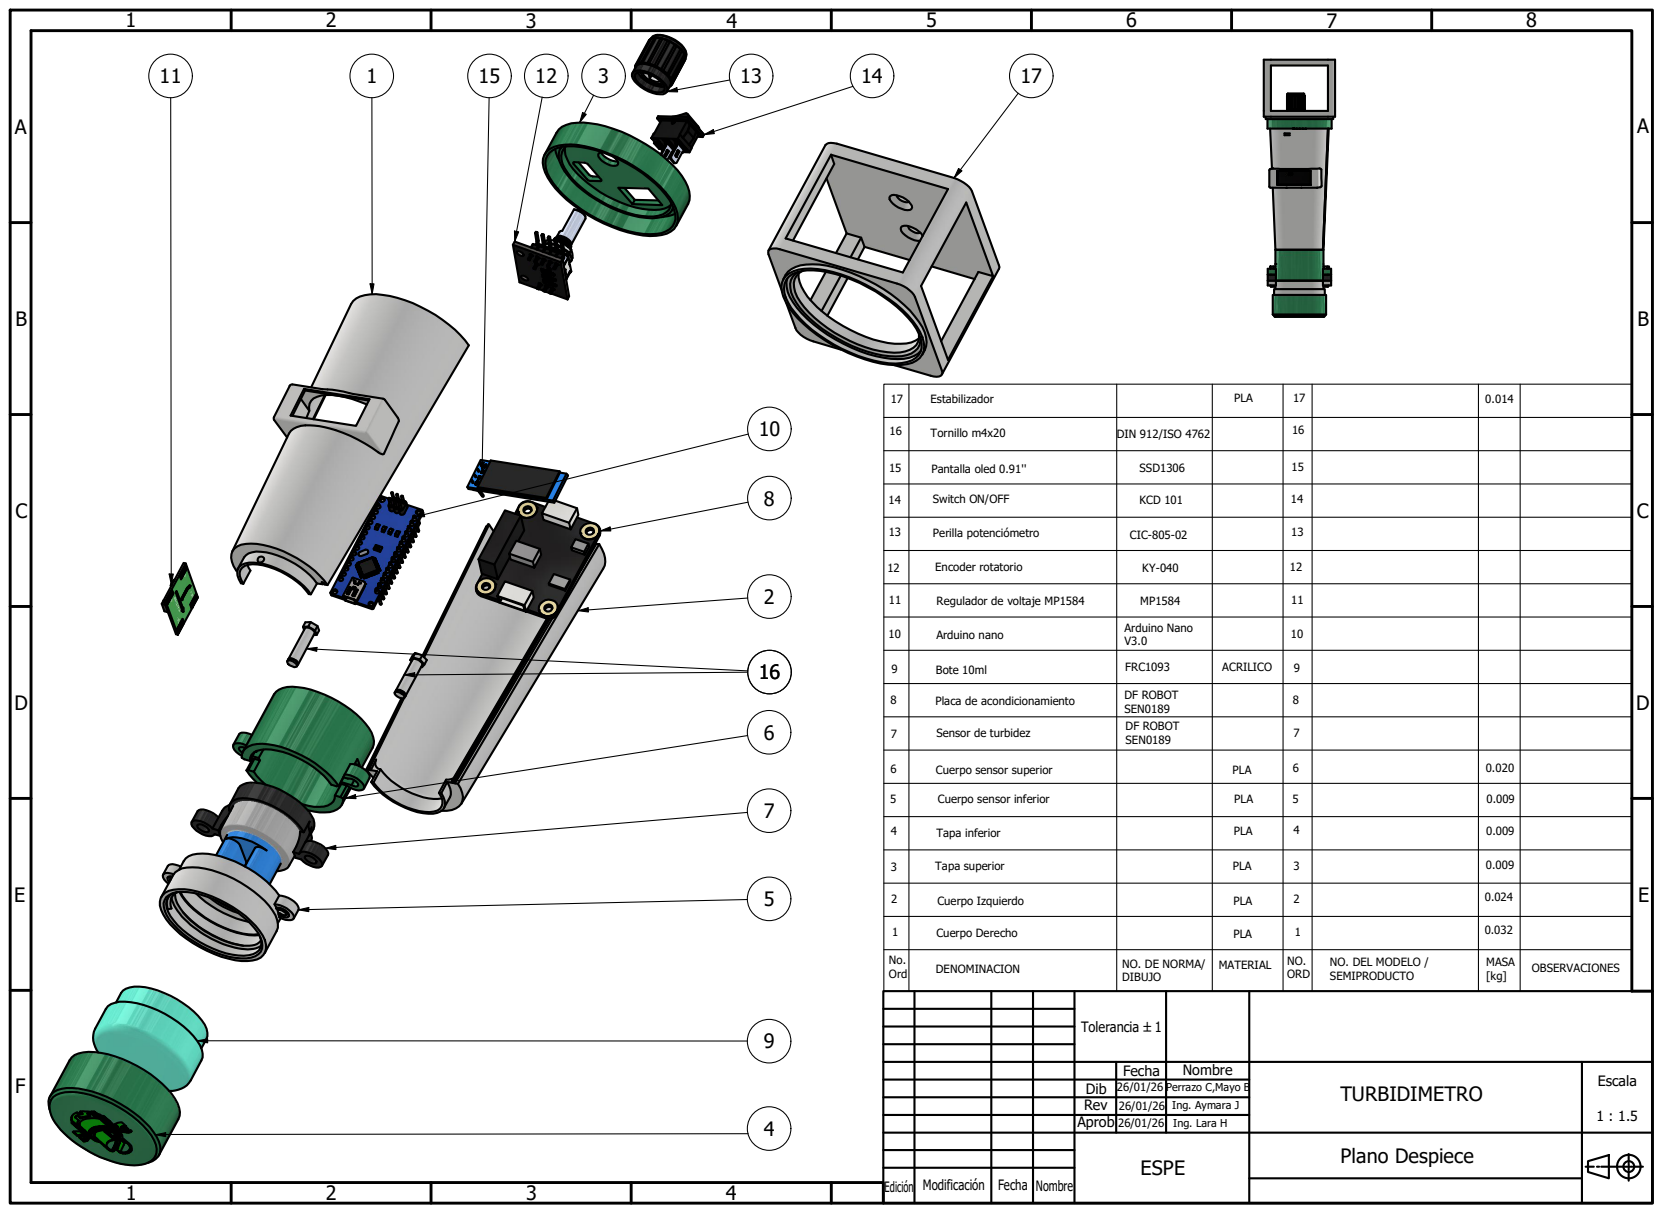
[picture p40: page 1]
Tolerancia `1

17 | Estabilizador | | PLA | 17 | 0.014

16 | Tornillo m4x20 | DIN 912/ISO 4762 | | 16

15 | Pantalla oled 0.91'' | SSD1306 | | 15

14 | Switch ON/OFF | KCD 101 | | 14

13 | Perilla potenciómetro | CIC-805-02 | | 13

12 | Encoder rotatorio | KY-040 | | 12

11 | Regulador de voltaje MP1584 | MP1584 | | 11

10 | Arduino nano | Arduino Nano V3.0 | | 10

9 | Bote 10ml | FRC1093 | ACRILICO | 9

8 | Placa de acondicionamiento | DF ROBOT SEN0189 | | 8

7 | Sensor de turbidez | DF ROBOT SEN0189 | | 7

6 | Cuerpo sensor superior | | PLA | 6 | 0.020

5 | Cuerpo sensor inferior | | PLA | 5 | 0.009

4 | Tapa inferior | | PLA | 4 | 0.009

3 | Tapa superior | | PLA | 3 | 0.009

2 | Cuerpo Izquierdo | | PLA | 2 | 0.024

1 | Cuerpo Derecho | | PLA | 1 | 0.032

NO. DE NORMA/
DIBUJO

NO. DEL MODELO /
SEMIPRODUCTO

Fecha | Nombre | TURBIDIMETRO | Escala 1 : 1.5
Dib | 26/01/26 Perrazo C,Mayo B
Rev | 26/01/26 | Ing. Aymara J
Aprob | 26/01/26 | Ing. Lara H

ESPE | Plano Despiece

Edición | Modificación | Fecha | Nombre

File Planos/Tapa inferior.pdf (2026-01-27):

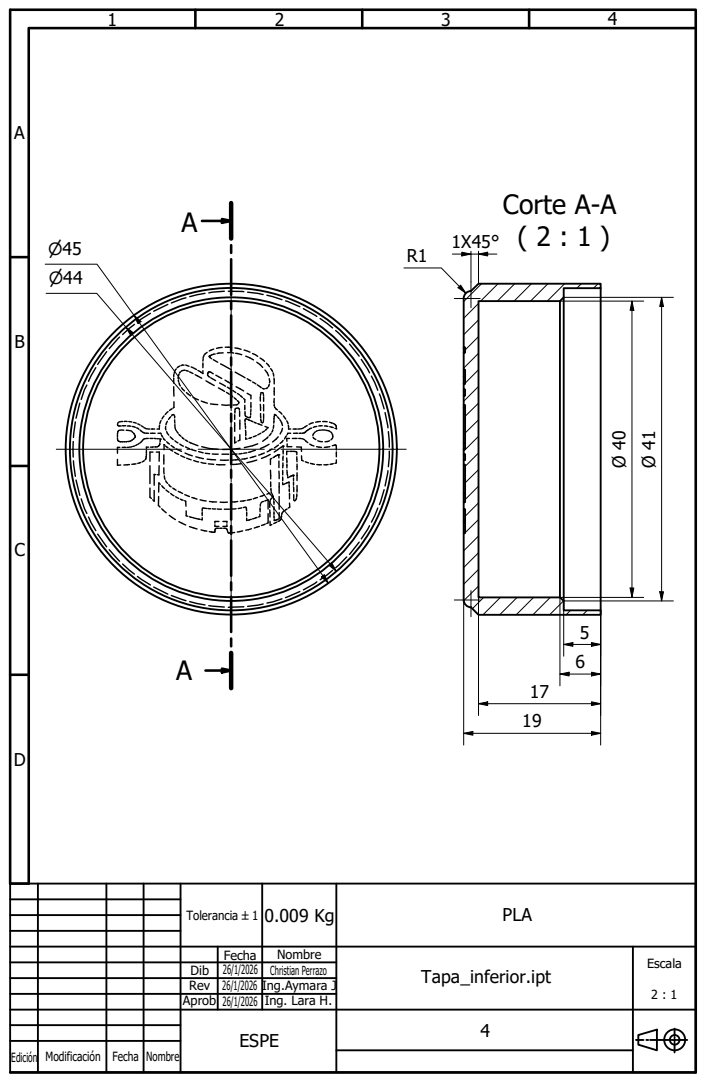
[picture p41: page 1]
Corte A-A ( 2 : 1 )

Tolerancia `1 | 0.009 Kg | PLA

Fecha | Nombre | Tapa_inferior.ipt | Escala 2 : 1
Dib | 26/1/2026 | Christian Perrazo
Rev | 26/1/2026 | Ing.Aymara J
Aprob | 26/1/2026 | Ing. Lara H.

ESPE | 4

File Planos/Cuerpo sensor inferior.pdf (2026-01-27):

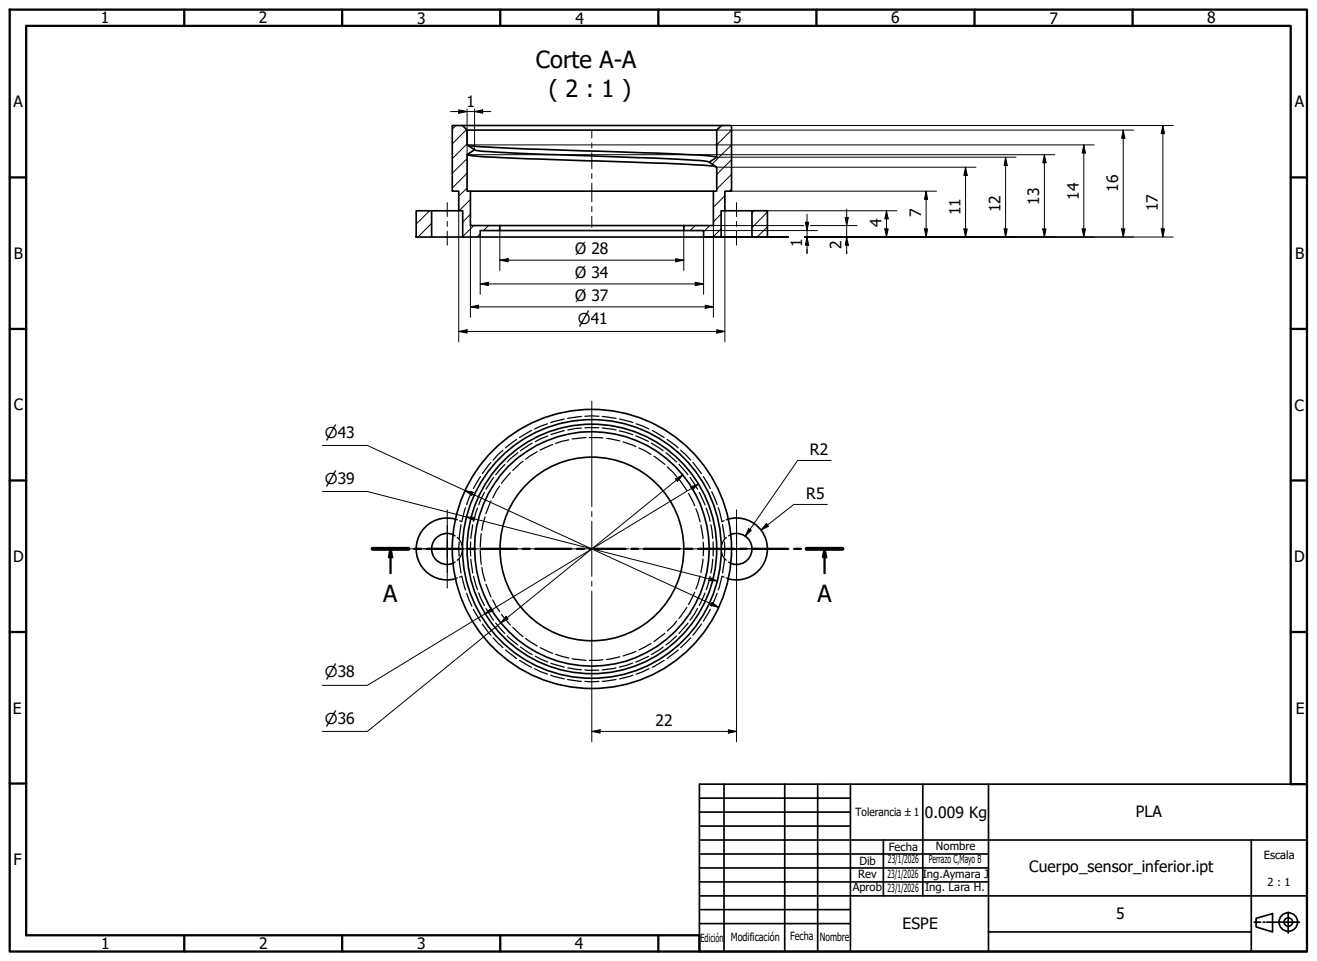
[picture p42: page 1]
Corte A-A ( 2 : 1 ); Tolerancia `1

Fecha | Nombre | Cuerpo_sensor_inferior.ipt | Escala 2 : 1
Dib | 23/1/2026 | Perrazo C,Mayo B
Rev | 23/1/2026 | Ing.Aymara J
Aprob | 23/1/2026 | Ing. Lara H.

ESPE | 5

Edición | Modificación | Fecha | Nombre

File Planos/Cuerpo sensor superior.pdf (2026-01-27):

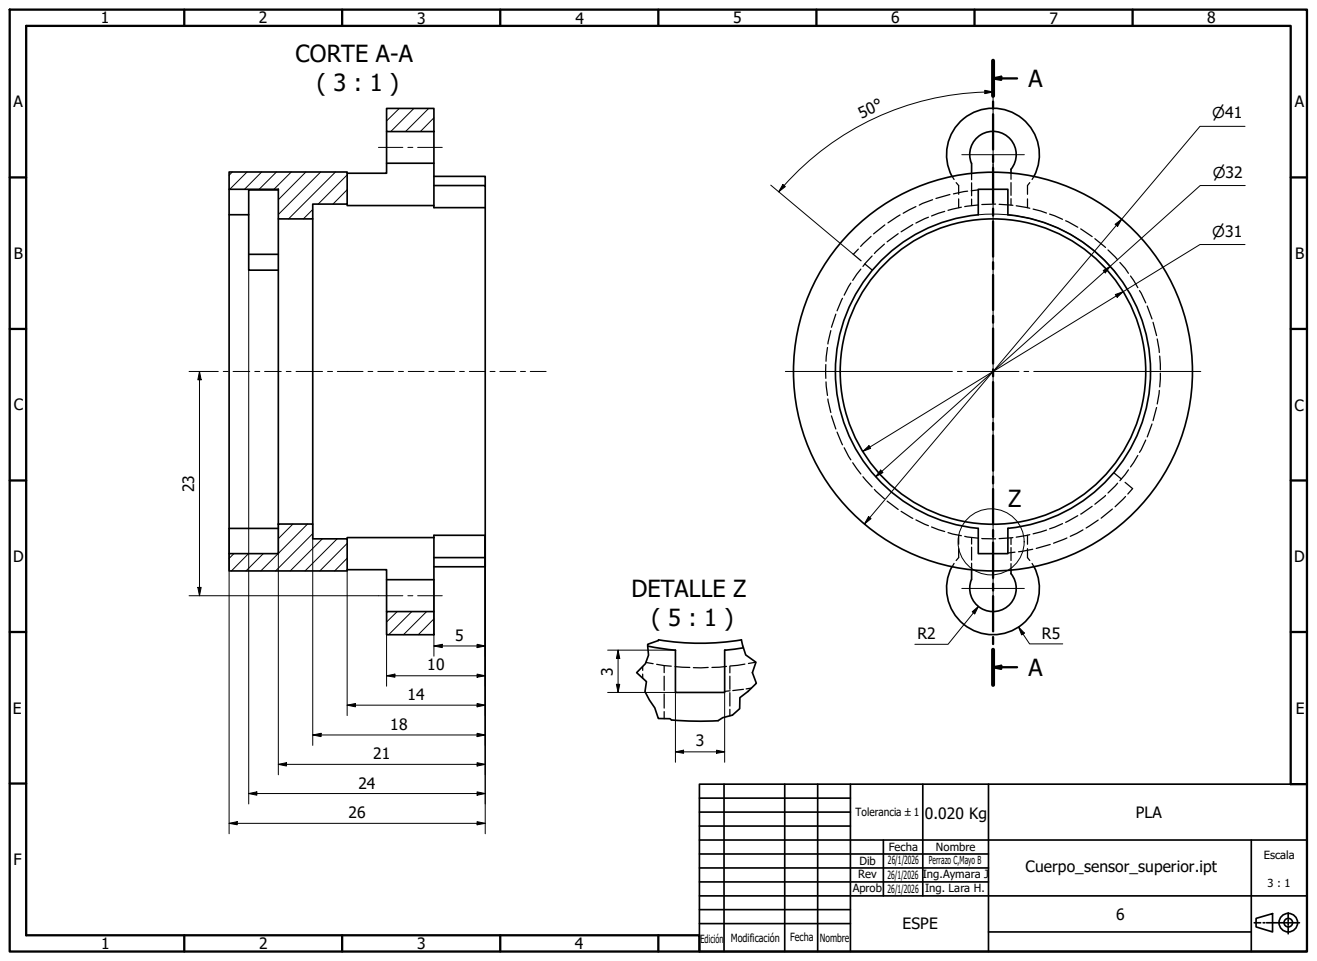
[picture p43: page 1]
CORTE A-A ( 3 : 1 ); DETALLE Z ( 5 : 1 ); Tolerancia `1

Fecha | Nombre | Cuerpo_sensor_superior.ipt | Escala 3 : 1
Dib | 26/1/2026 | Perrazo C,Mayo B
Rev | 26/1/2026 | Ing.Aymara J
Aprob | 26/1/2026 | Ing. Lara H.

ESPE | 6

Edición | Modificación | Fecha | Nombre

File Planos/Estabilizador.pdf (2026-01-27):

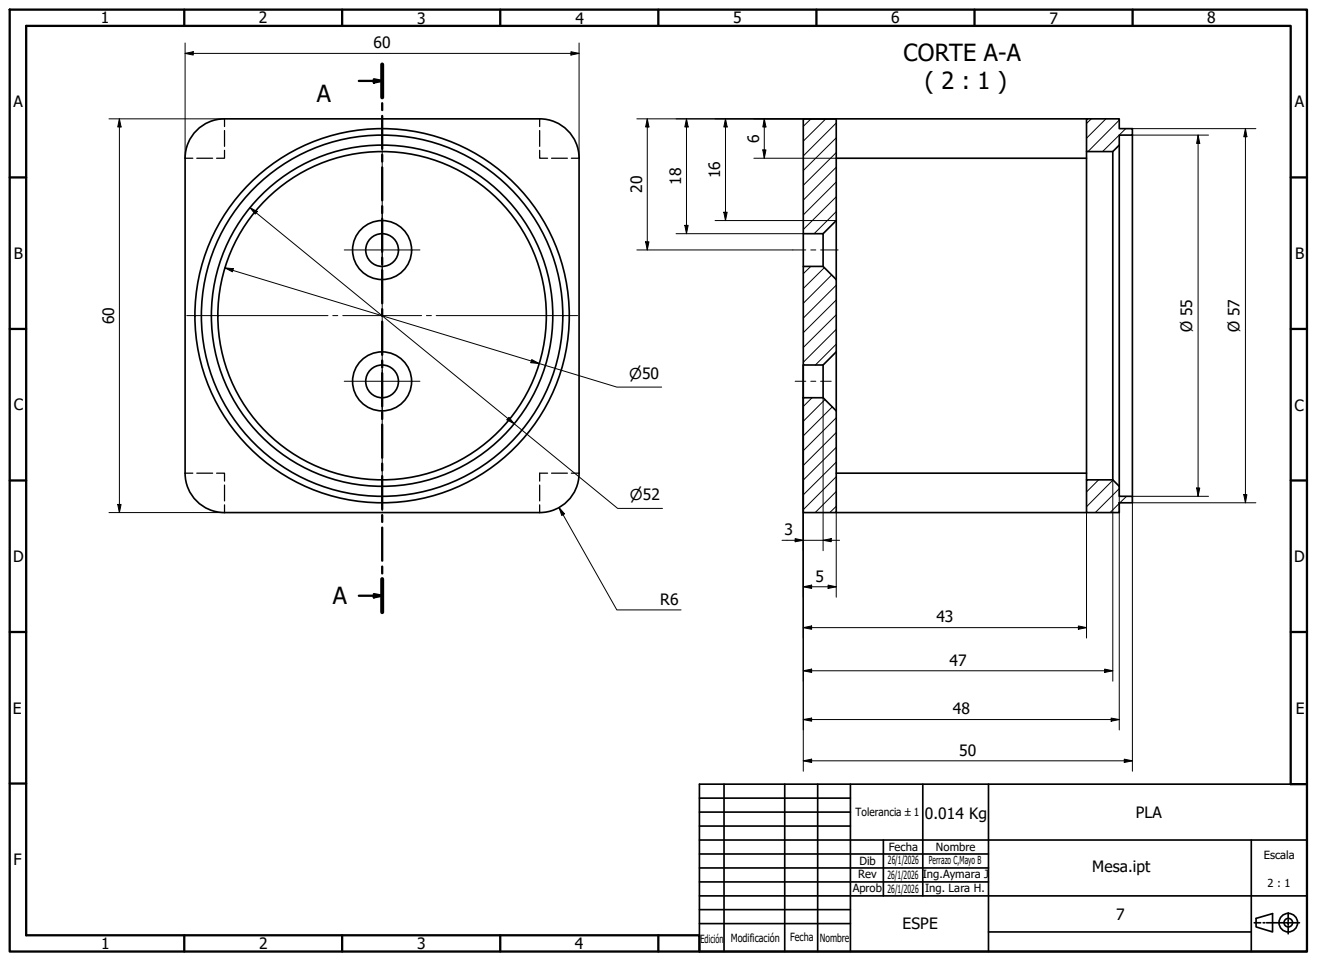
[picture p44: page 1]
CORTE A-A ( 2 : 1 ); Tolerancia `1

Fecha | Nombre | Mesa.ipt | Escala 2 : 1
Dib | 26/1/2026 | Perrazo C,Mayo B
Rev | 26/1/2026 | Ing.Aymara J
Aprob | 26/1/2026 | Ing. Lara H.

ESPE | 7

Edición | Modificación | Fecha | Nombre

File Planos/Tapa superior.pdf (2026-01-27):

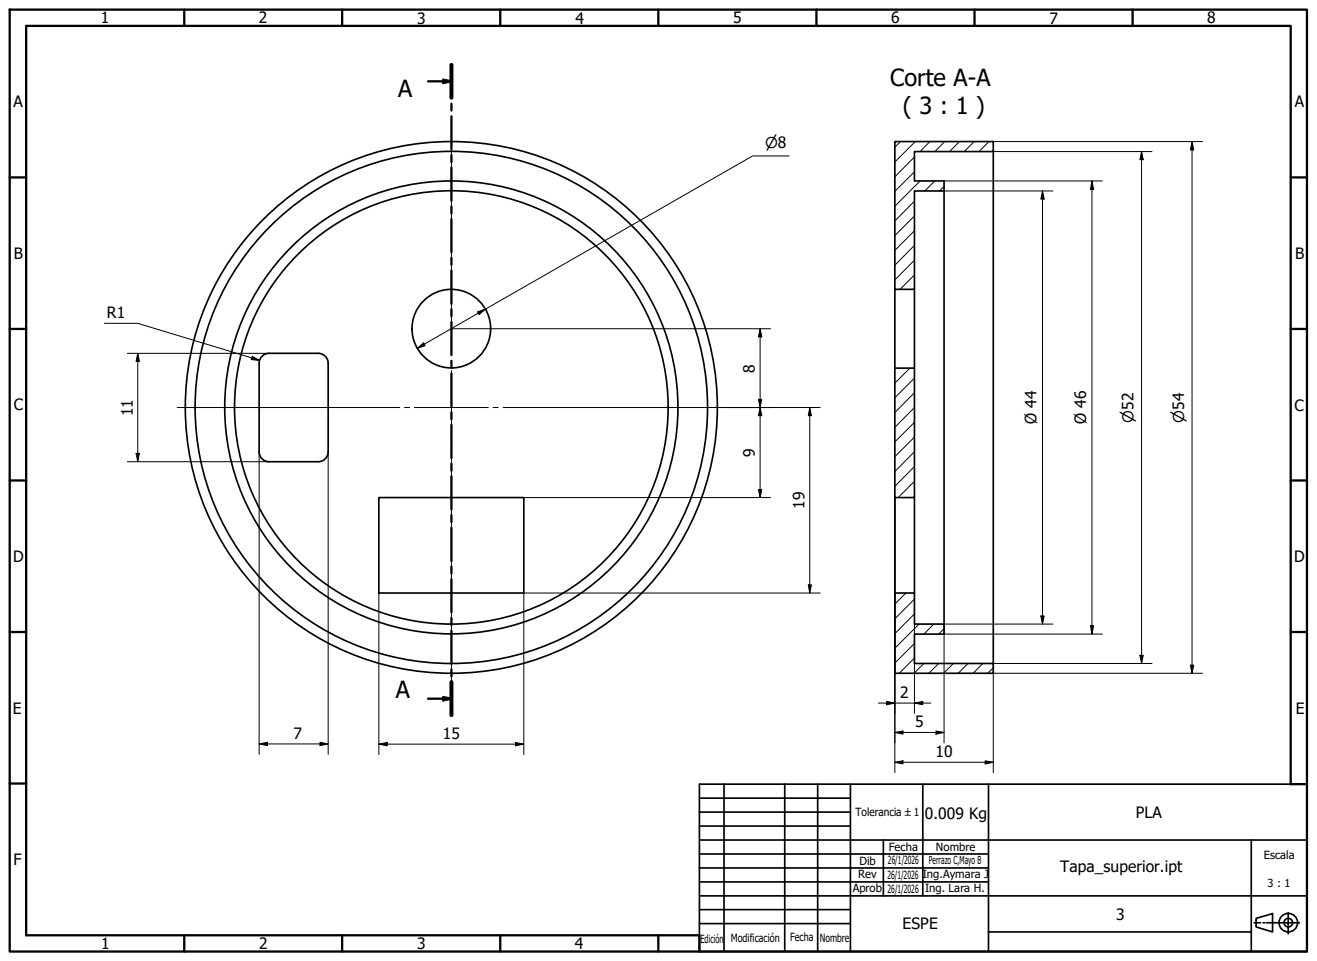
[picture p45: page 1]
Corte A-A ( 3 : 1 ); Tolerancia `1

Fecha | Nombre | Tapa_superior.ipt | Escala 3 : 1
Dib | 26/1/2026 | Perrazo C,Mayo B
Rev | 26/1/2026 | Ing.Aymara J
Aprob | 26/1/2026 | Ing. Lara H.

ESPE | 3

Edición | Modificación | Fecha | Nombre

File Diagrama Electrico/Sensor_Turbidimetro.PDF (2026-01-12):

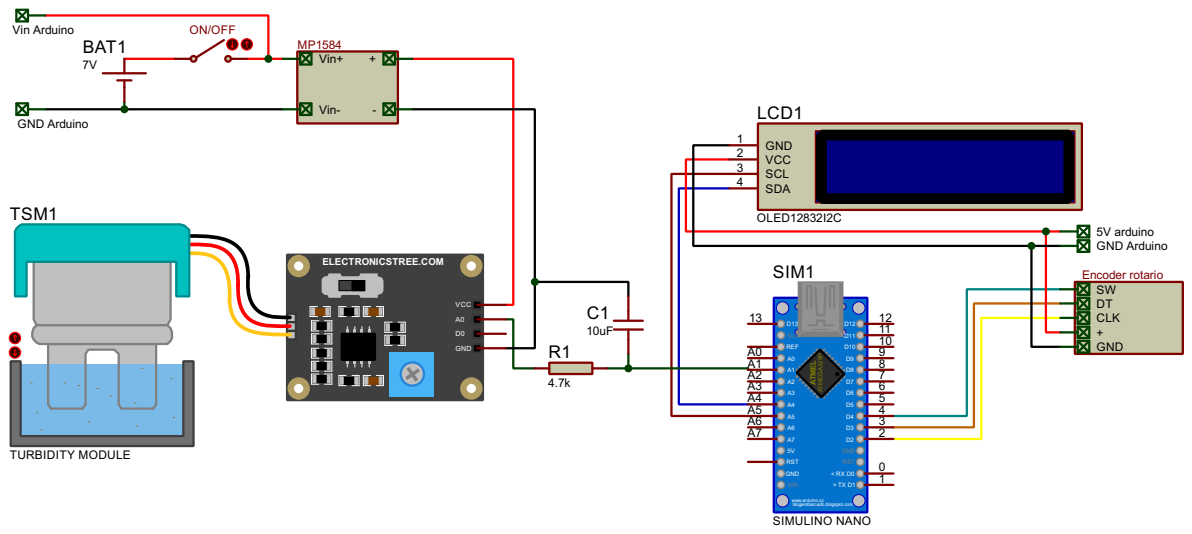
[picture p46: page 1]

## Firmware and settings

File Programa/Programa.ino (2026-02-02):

#include <U8g2lib.h> //Libreria para la pantalla oled
#include <avr/wdt.h> //Libreria para reinicio del arduino

// Definir pines
#define SENSOR_ANALOG_PIN A1    // Pin analógico del sensor de turbidez
#define ENCODER_A_PIN 2         // Pin A del encoder rotativo
#define ENCODER_B_PIN 3         // Pin B del encoder rotativo
#define ENCODER_SW_PIN 4        // Pin del switch del encoder

// Inicializar la pantalla OLED (128x32)
//U8G2_SSD1306_128X32_UNIVISION_F_HW_I2C u8g2(U8G2_R0, /* reset=*/ U8X8_PIN_NONE);
U8G2_SSD1306_128X32_UNIVISION_F_HW_I2C u8g2(U8G2_R2, /* reset=*/ U8X8_PIN_NONE); // Giro 180°

// Variable para la opción del menú (0: Medir NTU, 1: NTU Real Time, 2: Medir Directo, 3: Reiniciar)
int menuOption = 0;

// Variables para EMA
float smoothedValue = 0.0;
const float ALPHA = 0.1; // Factor de suavizado (0.05-0.2: más bajo = más suave)

// Para filtro mediano (array temporal)
const int MEDIAN_SAMPLES = 5; // Número impar para mediano
int readings[MEDIAN_SAMPLES];

// Para estabilización en Medir NTU
const int STAB_SAMPLES = 5; // Número de muestras para chequear estabilidad
const int STAB_THRESHOLD = 5; //10 // Máxima diferencia permitida para considerar estable
int stabBuffer[STAB_SAMPLES]; // Buffer para últimas lecturas
const unsigned long MIN_STAB_TIME = 30000;  // 30 segundos mínimo
const unsigned long MAX_STAB_TIME = 45000;  // 45 segundos máximo
const int READ_INTERVAL = 500;              // Intervalo entre lecturas (ms)

// Función para leer el sensor con filtro mediano + EMA
int readSmoothedSensor() {
  // Paso 1: Tomar múltiples lecturas rápidas
  for (int i = 0; i < MEDIAN_SAMPLES; i++) {
    readings[i] = analogRead(SENSOR_ANALOG_PIN);
    delayMicroseconds(100);
  }

  // Paso 2: Filtro mediano para eliminar outliers
  // Ordenar el array (burbuja simple, ya que es pequeño)
  for (int i = 0; i < MEDIAN_SAMPLES - 1; i++) {
    for (int j = 0; j < MEDIAN_SAMPLES - i - 1; j++) {
      if (readings[j] > readings[j + 1]) {
        int temp = readings[j];
        readings[j] = readings[j + 1];
        readings[j + 1] = temp;
      }
    }
  }
  int median = readings[MEDIAN_SAMPLES / 2];
  
  // Paso 3: Aplicar EMA sobre el mediano
  smoothedValue = (ALPHA * median) + ((1 - ALPHA) * smoothedValue);
  return (int)smoothedValue;
}

// Nueva función: selecciona la ecuación correcta según el valor raw
float calculateNTU(int sensorRaw) {
  float voltage = (sensorRaw / 1023.0) * 5.0;
  float NTU;

  if (sensorRaw > 930) {
    // Ecuación para valores altos (sensor en zona de baja transmisión)
    NTU = -2985.0 * pow(voltage, 2) + 26928.0 * voltage - 60699.0;
  } else {
    // Ecuación para rango normal
    NTU = 912.5 * pow(voltage, 3) - 11157.0 * pow(voltage, 2) + 44246.0 * voltage - 56263.0; //Sensor DF Robot
    //NTU = -21.10 * pow(voltage, 3) + 517.1 * pow(voltage, 2) - 3479 * voltage + 7142; //Sensor MJKDZ JD23-2
  }

  return (NTU < 0) ? 0.0 : NTU;
}

// Función para mostrar "cargando..." en pantalla
void showLoadingScreen() {
  u8g2.clearBuffer();
  u8g2.setFont(u8g2_font_ncenB10_tr);
  u8g2.drawStr(0, 20, "Cargando...");
  u8g2.sendBuffer();
}

// Función para esperar estabilización
int waitForStableReading() {
  showLoadingScreen();
  unsigned long startTime = millis();
  int index = 0;

  // Inicializar buffer
  for (int i = 0; i < STAB_SAMPLES; i++) {
    stabBuffer[i] = 0;
  }

  while (millis() - startTime < MAX_STAB_TIME) {
    int value = readSmoothedSensor();
    // Agregar al buffer (shift)
    for (int i = 0; i < STAB_SAMPLES - 1; i++) {
      stabBuffer[i] = stabBuffer[i + 1];
    }
    stabBuffer[STAB_SAMPLES - 1] = value;

    delay(READ_INTERVAL);

    // Solo chequear después de MIN_STAB_TIME y buffer lleno
    if (millis() - startTime >= MIN_STAB_TIME && index >= STAB_SAMPLES) {
      // Calcular max - min
      int minVal = stabBuffer[0];
      int maxVal = stabBuffer[0];
      for (int i = 1; i < STAB_SAMPLES; i++) {
        if (stabBuffer[i] < minVal) minVal = stabBuffer[i];
        if (stabBuffer[i] > maxVal) maxVal = stabBuffer[i];
      }
      if (maxVal - minVal <= STAB_THRESHOLD) {
        // Estable: retornar promedio
        long sum = 0;
        for (int i = 0; i < STAB_SAMPLES; i++) sum += stabBuffer[i];
        return sum / STAB_SAMPLES;
      }
    }
    index++;
  }
  // Si no estabiliza en 20s, retornar última lectura
  return stabBuffer[STAB_SAMPLES - 1];
}

// Función para mostrar la pantalla de bienvenida
void showWelcomeScreen() {
  u8g2.clearBuffer();
  u8g2.setFont(u8g2_font_ncenB10_tr); // Fuente grande
  u8g2.drawStr(0, 15, "TURBIDIMETRO");
  u8g2.drawStr(10, 32, "BIENVENIDO");
  u8g2.sendBuffer();
  delay(3000); // Mostrar durante 3 segundos
}

// Función para dibujar el menú con páginas
void drawMenu() {
  u8g2.clearBuffer();
  u8g2.setFont(u8g2_font_ncenB08_tr);// Fuente pequeña para mostrar más opciones
  if (menuOption < 3) {
    // Primera pantalla: Medir NTU, NTU Real Time, Medir Directo
    u8g2.drawStr(10, 10, menuOption == 0 ? "> Medir NTU" : " Medir NTU");
    u8g2.drawStr(10, 20, menuOption == 1 ? "> NTU Real Time" : " NTU Real Time");
    u8g2.drawStr(10, 30, menuOption == 2 ? "> Medir Directo" : " Medir Directo");
  } else {
    // Segunda pantalla: Reiniciar
    u8g2.drawStr(10, 10, menuOption == 3 ? "> Reiniciar" : " Reiniciar");
  }
  u8g2.sendBuffer();
}

// Función para leer el encoder rotativo
int readEncoder() {
  static int lastA = digitalRead(ENCODER_A_PIN);
  int currentA = digitalRead(ENCODER_A_PIN);
  if (currentA != lastA) {
    if (digitalRead(ENCODER_B_PIN) != currentA) {
      lastA = currentA;
      return 1; // Giro en sentido horario
    } else {
      lastA = currentA;
      return -1; // Giro en sentido antihorario
    }
  }
  return 0;
}

// Función para medir en tiempo real (valor raw)
void realTimeMeasurement() {
  while (digitalRead(ENCODER_SW_PIN) == HIGH) { // Salir con presión del switch
    int sensorValue = readSmoothedSensor();

    // Mostrar valor en el Serial
    Serial.print("Sensor Raw Value: ");
    Serial.println(sensorValue);

    // Mostrar valor en la pantalla OLED
    u8g2.clearBuffer();
    u8g2.setFont(u8g2_font_ncenB08_tr); // Fuente pequeña
    u8g2.drawStr(0, 10, "Valor Sensor:");
    u8g2.setFont(u8g2_font_ncenB14_tr); // Fuente grande para valor
    u8g2.setCursor(0, 25);
    u8g2.print(sensorValue);
    u8g2.setFont(u8g2_font_ncenB08_tr);
    u8g2.drawStr(60, 25, "(0-1023)");
    u8g2.sendBuffer();

    delay(500); // Actualizar cada 500ms para suavidad
  }
  delay(50);
  while (digitalRead(ENCODER_SW_PIN) == LOW); // Esperar liberación
}

// Medir NTU en tiempo real (con las dos ecuaciones)
void realTimeNTUMeasurement() {
  while (digitalRead(ENCODER_SW_PIN) == HIGH) { // Salir con presión del switch
    int sensorValue = readSmoothedSensor();
    float NTU = calculateNTU(sensorValue);

    Serial.print("NTU Real Time: ");
    Serial.println(NTU, 2);

    u8g2.clearBuffer();
    u8g2.setFont(u8g2_font_ncenB08_tr);
    u8g2.drawStr(0, 10, "NTU Real Time:");
    u8g2.setFont(u8g2_font_ncenB14_tr);
    u8g2.setCursor(0, 25);
    u8g2.print(NTU, 1);
    u8g2.setFont(u8g2_font_ncenB08_tr);
    u8g2.drawStr(60, 25, "NTU");
    u8g2.sendBuffer();

    delay(500); // Actualizar cada 500ms para suavidad
  }
  delay(50);
  while (digitalRead(ENCODER_SW_PIN) == LOW); // Esperar liberación
}

// Función para confirmar reinicio
bool confirmReset() {
  u8g2.clearBuffer();
  u8g2.setFont(u8g2_font_ncenB08_tr);
  u8g2.drawStr(0, 10, "Confirmar Reinicio?");
  u8g2.drawStr(0, 25, "Presione para OK");
  u8g2.sendBuffer();

  unsigned long startTime = millis();
  while (millis() - startTime < 5000) { // 5 segundos para confirmar
    if (digitalRead(ENCODER_SW_PIN) == LOW) {
      delay(50);
      while (digitalRead(ENCODER_SW_PIN) == LOW); // Esperar liberación
      return true; // Confirmado
    }
  }
  return false; // No confirmado
}

void setup() {
  Serial.begin(9600);
  // Inicializar la pantalla OLED
  u8g2.begin();

  // Configurar pines del encoder como entradas
  pinMode(ENCODER_A_PIN, INPUT);
  pinMode(ENCODER_B_PIN, INPUT);
  pinMode(ENCODER_SW_PIN, INPUT_PULLUP); // Switch con pull-up interno

  // Deshabilitar el watchdog al inicio
  wdt_disable();

  // Inicializar smoothedValue con una lectura inicial
  smoothedValue = analogRead(SENSOR_ANALOG_PIN);
  
  // Mostrar la pantalla de bienvenida
  showWelcomeScreen();
  
  // Mostrar el menú inicial
  drawMenu();
}

void loop() {
  // Leer el encoder para navegar el menú
  int enc = readEncoder();
  if (enc != 0) {
    menuOption += enc;
    if (menuOption < 0) menuOption = 3; // Limitar a 0-3 y ciclar
    if (menuOption > 3) menuOption = 0;
    drawMenu();
  }

  // Leer el switch del encoder para seleccionar la opción
  if (digitalRead(ENCODER_SW_PIN) == LOW) { // Switch activo en bajo
    delay(50);
    while (digitalRead(ENCODER_SW_PIN) == LOW); // Esperar a que se suelte

    if (menuOption == 0) {
      // Opción "Medir NTU": Esperar estabilización y mostrar NTU
      int sensorValue = waitForStableReading();
      float NTU = calculateNTU(sensorValue);

      // Valores en el serial
      Serial.print("Sensor Raw Value: "); Serial.println(sensorValue);
      Serial.print("Voltage: "); Serial.print((sensorValue / 1023.0) * 5.0, 3); Serial.println(" V"); // Muestra 3 decimales
      Serial.print("NTU: "); Serial.println(NTU, 2);// Muestra 2 decimales

      // Determinar el mensaje según el valor de NTU
      String message;
      if (NTU < 5)        message = "Excelente";
      else if (NTU < 15)  message = "Aceptable";
      else if (NTU < 100) message = "Precaucion";
      else                message = "No aceptable";

      // Pantalla 1: Mostrar valor de turbidez
      u8g2.clearBuffer();
      u8g2.setFont(u8g2_font_ncenB08_tr);// Fuente pequeña
      u8g2.drawStr(0, 10, "Turbidez:");
      u8g2.setFont(u8g2_font_ncenB14_tr);// Fuente grande para NTU
      u8g2.setCursor(0, 25);
      u8g2.print(NTU, 1);// Mostrar NTU con 1 decimal
      u8g2.setFont(u8g2_font_ncenB08_tr);
      u8g2.drawStr(60, 25, "NTU");
      u8g2.sendBuffer();

      // Esperar presión del switch para mostrar categoría
      while (digitalRead(ENCODER_SW_PIN) == HIGH); // Esperar presión
      delay(50);
      while (digitalRead(ENCODER_SW_PIN) == LOW); // Esperar liberación

      // Pantalla 2: Mostrar categoría
      u8g2.clearBuffer();
      u8g2.setFont(u8g2_font_ncenB12_tr);
      u8g2.drawStr(0, 16, "Categoria:");
      u8g2.drawStr(0, 32, message.c_str());
      u8g2.sendBuffer();

      // Esperar presión del switch para volver al menú
      while (digitalRead(ENCODER_SW_PIN) == HIGH);  // Esperar presión
      delay(50);
      while (digitalRead(ENCODER_SW_PIN) == LOW); // Esperar liberación

      drawMenu(); // Volver al menú
    }
    else if (menuOption == 1) {
      // Opción "NTU Real Time": Medir NTU en tiempo real
      realTimeNTUMeasurement();
      drawMenu(); // Volver al menú
    }
    else if (menuOption == 2) {
      // Opción "NTU Real Time": Medir en tiempo real (raw)
      realTimeMeasurement();
      drawMenu(); // Volver al menú
    }
    else if (menuOption == 3) {
      // Opción "Reiniciar": Confirmar y reiniciar el Arduino
      if (confirmReset()) {
        wdt_enable(WDTO_15MS); // Habilitar watchdog con timeout de 15ms
        while (1); // Esperar el reinicio
      }
      drawMenu(); // Volver al menú si no se confirma
    }
  }
}
